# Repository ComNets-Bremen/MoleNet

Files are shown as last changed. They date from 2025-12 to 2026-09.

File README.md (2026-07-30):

# MoleNet: A Wireless Underground Sensor Network Platform

MoleNet Logo

**MoleNet** is a versatile Wireless Underground Sensor Network (WUSN) platform designed for education and low-power environmental monitoring.
This repository contains all relevant resources, including PCB layouts, source code, and examples to test and evaluate the platform.

Further information can be found on the official [MoleNet Website](https://molenet.org/)!

> ⚠️ **Note:** This is an active project. The files and directory structure are subject to change.

## New ESP32-based MoleNet!

After a long journey, we are finally at a point where we are testing the current version on a larger scale.
The latest version of MoleNet features several key improvements:

- **ESP32-S3 microcontroller**: A powerful yet energy-efficient processor that supports various development ecosystems including [MicroPython](https://micropython.org/), [Arduino](https://www.arduino.cc/), and [RiotOS](https://www.riot-os.org/)
- **SDI-12 sensor interface**: Compatible with high-quality environmental sensors
- **Micro-SD card support**: Enables extensive local data storage
- **SX1276-based LoRa transceiver**: Provides long-range wireless communication
- **On-board BME280 sensor**: Measures temperature, barometric pressure, and humidity [BME280](https://www.bosch-sensortec.com/products/environmental-sensors/humidity-sensors-bme280/)
- **Low-power design**: Ensures long battery life for extended deployments
- **qwiic connectivity**: Simplifies integration of I2C-based sensors, as, for
  example, available here: [Sparkfun](https://www.sparkfun.com/qwiic)

## Documentation

New users can start with the **[Getting Started Guide](doc/GETTING_STARTED.md)** to identify their board version and find the correct software, hardware documentation, and setup instructions.

The main documentation of MoleNet is available [here in the doc directory](doc). There, you can also find the **[FAQ](doc/FAQ.md)**.

## Older Versions of MoleNet (pre-ESP)

In the past decade, we used and evaluated different microcontroller platforms
for MoleNet. The documentation can be found in the corresponding directories:

- [For ATMEGA-based boards](doc/ATMEGA)
- [For the STM32-based boards (STM32F411)](doc/stm32)

## Changelog

The list of changes and the evolution of MoleNet is listed in the
[changelog](CHANGELOG.md).

## Publications

The following list gives some MoleNet-related publications:

- Gellhaar, M., Dede, J., Koehler, H., & Förster, A. (2016, February). Design and Evaluation of Underground Wireless Sensor Networks for Reforestation Monitoring. [In EWSN (pp. 229-230)](https://dl.acm.org/doi/10.5555/2893711.2893747).
- Zaman, I., Dede, J., Gellhaar, M., Koehler, H., & Foerster, A. (2016). Molenet: A new sensor node for underground monitoring. [IEEE SenseApp](https://www.researchgate.net/publication/309397324_MoleNet_A_New_Sensor_Node_for_Underground_Monitoring).
- Zaman, I., Gellhaar, M., Dede, J., Koehler, H., & Foerster, A. (2016, November). Design and evaluation of MoleNet for wireless underground sensor networks. In 2016 IEEE 41st conference on local computer networks workshops (LCN workshops) (pp. 145-147), [2016 IEEE 41st Conference on Local Computer Networks Workshops (LCN Workshops), Dubai, United Arab Emirates, 2016, pp. 145-147](https://doi.org/10.1109/LCN.2016.040).
- Dede, J., Helms, D., & Förster, A. (2021). MoleNet: An Underground Sensor Network for Soil Monitoring. [Electronic Communications of the EASST, 80](https://doi.org/10.14279/tuj.eceasst.80.1132)
- Sambo, D. W., Dede, J., Mitton, N., & Förster, A. (2023). FuzDeMa: A portable Fuzzy-based Decision-Making tool for reliable communication in Wireless Underground Sensor Networks. [ITU Journal on Future and Evolving Technologies, 4(3), 419-433](https://www.doi.org/10.52953/IXIP2995).
- Block, J., Könsgen, A., Dede, J., Förster, A. (2026, January). Precise Low-Current Measurement Techniques for IoT Devices: A Case Study on MoleNet. [arxiv, Electrical Engineering and Systems Science > Signal Processing](https://doi.org/10.48550/arXiv.2601.16727)

## I need Support or want to Contribute!

The development of MoleNet is mainly done on GitHub. You have the following
channels:

- For discussions, we are currently trying to move from our mailing list to [GitHub discussions](https://github.com/ComNets-Bremen/MoleNet/discussions). Feel free to join and open new discussions directly [here](https://github.com/ComNets-Bremen/MoleNet/discussions)!
- You found an issue? [Open an Issue on GitHub](https://github.com/ComNets-Bremen/MoleNet/issues)!
- You already have a solution? Perfect! Feel free to [create a Pull request on GitHub](https://github.com/ComNets-Bremen/MoleNet/pulls)!

If you need support with the git fundamentals like cloning, forking, branching,
the different copies of the code etc., please refer to the [GitHub
documentation](https://docs.github.com).

## I want to have MoleNet!

MoleNet is a dynamic project that is constantly evolving. At its current stage, we do not offer a ready-to-use, fully certified product with complete end-user support.

If you would like to contribute to the development of MoleNet and need hardware for testing and further development, you have two options:

1. **Build the hardware yourself.** All the necessary resources can be found in this repository.
2. **Order evaluation boards** from our partner [Intergalactic Circuits](https://intergalactic-circuits.de) for personal use.

## Contributors

Many students and researchers contribute to the MoleNet project.
See the full list of contributors in [CONTRIBUTORS.md](CONTRIBUTORS.md).

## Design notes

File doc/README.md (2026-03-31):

# Documentation

This directory contains the documentation of MoleNet. For the previous
versions, please refer to the [ATMEGA](ATMEGA) or [stm32](stm32) directory, respectively.

Maybe you are looking for our **[FAQ](FAQ.md)**?

# The Hardware

MoleNet 6.1 with all available components assembled. Click on the image for a
high resolution version.

The MoleNet 6.3 hardware

## Available Components

- LoRa via
  - [SX1276](https://www.semtech.com/products/wireless-rf/lora-connect/sx1276) [Ra-01H](https://docs.ai-thinker.com/en/Ra-01H/) module till MoleNet 6.3
  - [SX1262](https://www.semtech.com/products/wireless-rf/lora-connect/sx1262) [RA-01SH](https://docs.ai-thinker.com/en/Ra-01SH/index.html) module since MoleNet 7.0
- [BME280](https://www.bosch-sensortec.com/products/environmental-sensors/humidity-sensors-bme280/)
- SD-card holder
- [qwiic](https://www.sparkfun.com/qwiic) for external I2C components
- LEDs
- [SDI-12](https://www.sdi-12.org/) for environmental sensors
- Additional pins (analog and digital)

## Components and their Connections

MoleNet contains various different on-board parts. The following tables list
the connections and other relevant information for the major parts. For further
details, refer to [schematics of the corresponding board](../PCB-Layouts/).

- [Table MoleNet 7.1](hw_doc/7.1.md)
- [Table MoleNet 7.0](hw_doc/7.0.md)
- [Table MoleNet 6.3](hw_doc/6.3.md)
- [Table MoleNet 6.2](hw_doc/6.2.md)

**Please check also the [CHANGELOG](../CHANGELOG.md) for further changes and issues**

## Pins on the ESP32

For the usage of the pins, please refer to the hardware section in this
document or the schematics of the corresponding versions available in [the PCB-Layouts directory](../PCB-Layouts/).

# Setup using Arduino

1) Install **Arduino IDE** -> [arduino.cc](https://www.arduino.cc/en/software/)
2) Install the **esp32** package by Espressif via the **Boards Manager** in the IDE
3) Select the **ESP32S3 Dev Module** as the board
4) Select the corresponding USB port
5) Set USB CDC On Boot: Enabled
6) Set USB Mode: USB-OTG (Tiny USB)

**⚠️ Attention: Different ports!**

Different ports are created at various times when the MoleNet platform is connected to the computer. One port is to flash the firmware, while the second is to access the MoleNet Platform’s serial port. The first is the default after a reset. The second is usually entered if the boot button is pressed during reset or when powering up the board.

Usually, you have to setup the board twice according to the settings above. Be
aware that the port identifier can change depending on your operating system.

# Setup using MicroPython

Please use the documentation for the ESP32 available at
[micropython.org](https://micropython.org/download/ESP32_GENERIC_S3/).

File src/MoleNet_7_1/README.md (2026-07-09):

# MoleNet v7.1 Test Files

This folder contains basic test files for the MoleNet v7.1 ESP32-S3 board.

## Folder Structure

* `lib/`
  Common MicroPython libraries used by the test scripts.

* `deep_sleep_test/`
  Minimal test to measure board + LoRa deep sleep current.

* `lorawan_connection_test/`
  Minimal ABP and OTAA scripts to test LoRaWAN connection with TTN.

## Notes

* The `lib/` folder does not contain `main.py`.
* Use only one test script as `main.py` on the board at a time.
* Copy the required files from `lib/` to the board together with the selected test script.
* The onboard BME280 is not used in these minimal tests.
* External sensors are not required for these tests.

## Included Tests

### Deep Sleep Test

Used to measure the deep sleep current of:

* MoleNet board + LoRa module
* MoleNet board only, if LoRa VDD / RA_VDD is disconnected

### LoRaWAN Connection Test

Used to check if the MoleNet v7.1 board can send data to TTN using:

* ABP
* OTAA

The LoRaWAN test sends:

`hello`

to TTN.

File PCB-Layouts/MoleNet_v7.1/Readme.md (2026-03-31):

This folder contain Kicad files of Molenet V7.1 Board.

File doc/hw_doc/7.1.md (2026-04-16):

# Components and their Connections: MoleNet 7.1

This table gives an overview of the used components and their connections.
Please also refer to the corresponding schematic:

[MoleNet 7.1 Schematic](../../PCB-Layouts/MoleNet_v7.1/Molenet_V7.1_Schematic.pdf)

| **Part** | **Part Number** | **Description** | **Pins** |
|---|---|---|---|
| SW1 | SKHHARA010 | Reset button (enable) for ESP32 | EN |
| SW2 | SKHHARA010 | Boot mode button for ESP32 | GPIO0 |
| U1 | [ESP32-S3-WROOM-1-N16](https://www.espressif.com/sites/default/files/documentation/esp32-s3-wroom-1_wroom-1u_datasheet_en.pdf) | ESP32-S3 | |
| U3 | [TLV76133DCYR](https://www.ti.com/product/de-de/TLV761/part-details/TLV76133DCYR) | Voltage regulator 3V3, 1N5819 between Vin and the regulator (D1) | |
| U5 | Ra-01SH | LoRa Module ([SX1262](https://www.semtech.com/products/wireless-rf/lora-connect/sx1262), [RA-01SH](https://docs.ai-thinker.com/en/Ra-01SH/index.html)) | RESET=GPIO15, NSS=GPIO48, MOSI=GPIO47, MISO=GPIO21, SCK=GPIO14, DIO1=GPIO46, BUSY/DIO4=GPIO39 |
| U7 | [BME280](https://www.bosch-sensortec.com/products/environmental-sensors/humidity-sensors-bme280/) | Sensor for humidity, barometric pressure and ambient temperature | I2C, SCL=GPIO8, SDA=GPIO9, address=0x76 (shared with qwiic connector) |
| D6 | NCD0805R1 | User LED | GPIO38 |
| D7 | NCD0805R1 | User LED | GPIO2 |
| D8 | NCD0805R1 | Power LED | Power |
| J1 | | Enable SD-card via jumpers | Power=GPIO7 (optional), MOSI=GPIO11, MISO=GPIO13, SCK=GPIO12, CS=GPIO10. You can select the power by one jumper: directly powered or via GPIO. |
| J2 | | Enable BME280 connection via jumpers | |
| J3 | | Power out | 2xGND, 3V3, Vin |
| J4 | | Enable LEDs via jumpers | |
| J5 | | Enable LoRa via jumpers | |
| J6 | | USB connector. Uses the ESP32 internal USB (D+, D-), use USB-CDC on boot / USB-OTG with TinyUSB (depending on your needs / system)| |
| J7 | | Power in, 5-7V | |
| J8 | | Misc. pins (ADC etc.) | |
| J9 | | Unused GPIOs | |
| J10 | | SDI-12 connector | Uses the following GPIOs: Power=GPIO1, SDI_RX_ENABLE=GPIO36, SDI_RX=GPIO18, SDI_TX_ENABLE=GPIO35, SDI_TX=GPIO17, SDI_MARKING=GPIO37 |
| J11 | | Remaining DIOs from LoRa transceiver | |
| J12 | | Power connector for energy measurements of the entire board. Connect via jumper | |
| J13 | | Micro SD card holder | |
| J14 | SMA-KWE902 | SMA connector for LoRa | |
| J15 | | qwiic connector for I2C devices | SCL=GPIO8, SDA=GPIO9 (shared with BME280) |
| J16 | | Power SDI-12 interface via jumper. Alternative: switch using GPIO1 | |
| J17 | | Jumper for ESP32 power supply. Used to measure only the power consumption of the ESP. Connect via jumper. | |

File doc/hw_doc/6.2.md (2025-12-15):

# Components and their Connections: MoleNet 6.2

This table gives an overview of the used components and their connections.
Please also refer to the corresponding schematic:

[MoleNet 6.2 Schematic](../../PCB-Layouts/MoleNet_v6.2/MoleNet V6.2/Molenet_V6.2_20_03_25_schematic.pdf)

| **Part** | **Part Number** | **Description** | **Pins** |
|---|---|---|---|
| SW1 | SKHHARA010 | Reset button (enable) for ESP32 | EN |
| SW2 | SKHHARA010 | Boot mode button for ESP32 | GPIO0 |
| U1 | [ESP32-S3-WROOM-1-N16](https://www.espressif.com/sites/default/files/documentation/esp32-s3-wroom-1_wroom-1u_datasheet_en.pdf) | ESP32-S3 | |
| U3 | [TLV76133DCYR](https://www.ti.com/product/de-de/TLV761/part-details/TLV76133DCYR) | Voltage regulator 3V3 | |
| U5 | Ra-01H | LoRa Module ([SX1276](https://www.semtech.com/products/wireless-rf/lora-connect/sx1276)) | RESET=GPIO55, NSS=GPIO48, MOSI=GPIO47, MISO=GPIO21, SCK=GPIO14, DIO0=GPIO46 |
| U7 | [BME280](https://www.bosch-sensortec.com/products/environmental-sensors/humidity-sensors-bme280/) | Sensor for humidity, barometric pressure and ambient temperature | I2C, SCL=GPIO8, SDA=GPIO9, address=0x76 |
| D6 | NCD0805R1 | User LED | GPIO38 |
| D7 | NCD0805R1 | User LED | GPIO2 |
| D8 | NCD0805R1 | Power LED | Power |
| J1 | | Enable SD-card via jumpers | Power=GPIO7 (optional), MOSI=GPIO11, MISO=GPIO13, SCK=GPIO12, CS=GPIO10 |
| J2 | | Enable BME280 connection via jumpers | |
| J3 | | Power out | GND, 3V3, Vin |
| J4 | | Enable LEDs via jumpers | |
| J5 | | Enable LoRa via jumpers | |
| J6 | | USB connector | |
| J7 | | Power in | |
| J8 | | Misc. pins (ADC etc.) | |
| J9 | | Unused GPIOs | |
| J10 | | SDI-12 connector | Uses the following GPIOs: Power=GPIO1, SDI_RX_ENABLE=GPIO36, SDI_RX=GPIO18, SDI_TX_ENABLE=GPIO35, SDI_TX=GPIO17, SDI_MARKING=GPIO37 |
| J11 | | Remaining DIOs from LoRa transceiver | |
| J12 | | Power connector for energy measurements of the entire board. Connect via jumper | |
| J13 | | Micro SD card holder | |
| J14 | SMA-KWE902 | SMA connector for LoRa | |
| J15 | | qwiic connector for I2C devices | SCL=GPIO8, SDA=GPIO9 (shared with BME280) |
| J16 | | Power SDI-12 interface via jumper. Alternative: switch using GPIO1 | |
| J17 | | Jumper for ESP32 power supply. Used to measure only the power consumption of the ESP. Connect via jumper. | |

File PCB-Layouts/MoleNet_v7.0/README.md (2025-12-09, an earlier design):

This folder contain Kicad files of Molenet V7 Board.

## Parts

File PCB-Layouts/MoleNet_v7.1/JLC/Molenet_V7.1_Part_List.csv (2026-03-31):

Designator | Footprint | Quantity | Value | JLC Part Number | Alternative
C1, C14 | 0805 | 2 | 22uF | C45783
C10, C5, C7, C9 | 0805 | 4 | 0.1uF | C49678
C13 | 0805 | 1 | 10uF | C15850
C15, C2 | 0805 | 2 | 100nF | C49678
C16 | 0402 | 1 | 22uF | C415703
C17 | 0402 | 1 | 100nF | C1525
C3, C6, C8 | 0805 | 3 | 1uF | C28323
C4 | 0805 | 1 | 2.2uF | C377773
D1, D3 | D_DO-41_SOD81_P10.16mm_Horizontal | 2 | 1N5819 | C2474
D2, D4, D5 | LESD5D50CT1G | 3 | LESD5D5.0CT1G | C383211 | C5199850
D6, D7, D8 | 0805 | 3 | LED | C84256
H1, H2, H3, H4 | MountingHole_3.2mm_M3_Pad | 4 | MountingHole_Pad
J1 | PinHeader_2x07_P2.54mm_Vertical | 1 | Micro SD connector | C71397
J10 | TerminalBlock_Phoenix_PT-1,5-3-3.5-H_1x03_P3.50mm_Horizontal | 1 | SDI-12 | C91152
J11 | PinHeader_1x06_P2.54mm_Vertical | 1 | RA_01_DIO | C6332199
J12, J16, J17 | PinHeader_1x02_P2.54mm_Vertical | 3 | Conn_01x02 | C492401
J13 | microSD_HC_Molex_104031-0811 | 1 | Micro SD Card | C428492 | C585350
J14 | SMA_Amphenol_901-143_Horizontal | 1 | Conn_Coaxial | C914554 | C1509213
J15 | SPARKFUN_PRT-14417 | 1 | Qwiic | C2859067 | C160404
J2 | PinHeader_2x04_P2.54mm_Vertical | 1 | BME280 Connector | C18078213
J3 | PinHeader_1x04_P2.54mm_Vertical | 1 | Power Out | C2691448
J4 | PinHeader_2x03_P2.54mm_Vertical | 1 | Led Connector | C7501274
J5 | PinHeader_2x08_P2.54mm_Vertical | 1 | Lora Connector | C18078217
J6 | USB_C_Receptacle_G-Switch_GT-USB-7010ASV | 1 | USB_C_Receptacle_USB2.0 | C2936185
J7 | TerminalBlock_Phoenix_PT-1,5-2-3.5-H_1x02_P3.50mm_Horizontal | 1 | 5V-16V Input | C695629
J8 | PinHeader_2x04_P2.54mm_Vertical | 1 | ~ | C18078213
J9 | PinHeader_2x08_P2.54mm_Vertical | 1 | Unused Pin | C18078217
Q1 | TO-92_Inline | 1 | BS170 | C111691
Q2 | SOT-23 | 1 | IRLML5203 | C5364310
R1, R2, R3, R6 | 0805 | 4 | 10k | C17414
R10, R11, R12, R8 | 0805 | 4 | 220 | C17557
R13, R14, R15, R16 | 0402 | 4 | 10K | C25744
R17, R7 | 0402 | 2 | 4.7K | C25900
R18, R19 | 0805 | 2 | 100k | C149504
R4, R5 | 0402 | 2 | 5.1k | C25905
R9 | 0805 | 1 | 1k | C17513
SW1 | SW_PUSH_6mm_H4.3mm | 1 | RESET | C139758 | C7470125
SW2 | SW_PUSH_6mm_H4.3mm | 1 | BOOT | C139758
U1 | ESP32-S3-WROOM-1 | 1 | ESP32-S3-WROOM-1 | C2913199
U2 | SC-74A-5_1.55x2.9mm_P0.95mm | 1 | 74AHC1G00 | C842261
U3 | SOT-223-3_TabPin2 | 1 | TLV76133DCY | C7527500
U4 | DIP-4_W7.62mm | 1 | PC817 | C3025068
U5 | Ai-Thinker-Ra-01-LoRa | 1 | Lora Module | C2764087
U6 | SOP65P400X130-8N | 1 | 74LVC2G241 | C2676069
U7 | Bosch_LGA-8_2.5x2.5mm_P0.65mm_ClockwisePinNumbering | 1 | BME280 | C92489

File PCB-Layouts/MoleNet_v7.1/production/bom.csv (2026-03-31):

Designator | Footprint | Quantity | Value | LCSC Part #
C1, C14 | 0805 | 2 | 22uF
C10, C5, C7, C9 | 0805 | 4 | 0.1uF
C13 | 0805 | 1 | 10uF
C15, C2 | 0805 | 2 | 100nF
C16 | 0402 | 1 | 22uF
C17 | 0402 | 1 | 100nF
C3, C6, C8 | 0805 | 3 | 1uF
C4 | 0805 | 1 | 2.2uF
D1, D3 | D_DO-41_SOD81_P10.16mm_Horizontal | 2 | 1N5819
D2, D4, D5 | LESD5D50CT1G | 3 | LESD5D5.0CT1G
D6, D7, D8 | 0805 | 3 | LED
H1, H2, H3, H4 | MountingHole_3.2mm_M3_Pad | 4 | MountingHole_Pad
J1 | PinHeader_2x07_P2.54mm_Vertical | 1 | Micro SD connector
J10 | TerminalBlock_Phoenix_PT-1,5-3-3.5-H_1x03_P3.50mm_Horizontal | 1 | SDI-12
J11 | PinHeader_1x06_P2.54mm_Vertical | 1 | RA_01_DIO
J12, J16, J17 | PinHeader_1x02_P2.54mm_Vertical | 3 | Conn_01x02
J13 | microSD_HC_Molex_104031-0811 | 1 | Micro SD Card
J14 | SMA_Amphenol_901-143_Horizontal | 1 | Conn_Coaxial
J15 | SPARKFUN_PRT-14417 | 1 | Qwiic
J2 | PinHeader_2x04_P2.54mm_Vertical | 1 | BME280 Connector
J3 | PinHeader_1x04_P2.54mm_Vertical | 1 | Power Out
J4 | PinHeader_2x03_P2.54mm_Vertical | 1 | Led Connector
J5 | PinHeader_2x08_P2.54mm_Vertical | 1 | Lora Connector
J6 | USB_C_Receptacle_G-Switch_GT-USB-7010ASV | 1 | USB_C_Receptacle_USB2.0
J7 | TerminalBlock_Phoenix_PT-1,5-2-3.5-H_1x02_P3.50mm_Horizontal | 1 | 5V-16V Input
J8 | PinHeader_2x04_P2.54mm_Vertical | 1 | ~
J9 | PinHeader_2x08_P2.54mm_Vertical | 1 | Unused Pin
Q1 | TO-92_Inline | 1 | BS170
Q2 | SOT-23 | 1 | IRLML5203
R1, R2, R3, R6 | 0805 | 4 | 10k
R10, R11, R12, R8 | 0805 | 4 | 220
R13, R14, R15, R16 | 0402 | 4 | 10K
R17, R7 | 0402 | 2 | 4.7K
R18, R19 | 0805 | 2 | 100k
R4, R5 | 0402 | 2 | 5.1k
R9 | 0805 | 1 | 1k
SW1 | SW_PUSH_6mm_H4.3mm | 1 | RESET
SW2 | SW_PUSH_6mm_H4.3mm | 1 | BOOT
U1 | ESP32-S3-WROOM-1 | 1 | ESP32-S3-WROOM-1
U2 | SC-74A-5_1.55x2.9mm_P0.95mm | 1 | 74AHC1G00
U3 | SOT-223-3_TabPin2 | 1 | TLV76133DCY
U4 | DIP-4_W7.62mm | 1 | PC817
U5 | Ai-Thinker-Ra-01-LoRa | 1 | Lora Module
U6 | SOP65P400X130-8N | 1 | 74LVC2G241
U7 | Bosch_LGA-8_2.5x2.5mm_P0.65mm_ClockwisePinNumbering | 1 | BME280

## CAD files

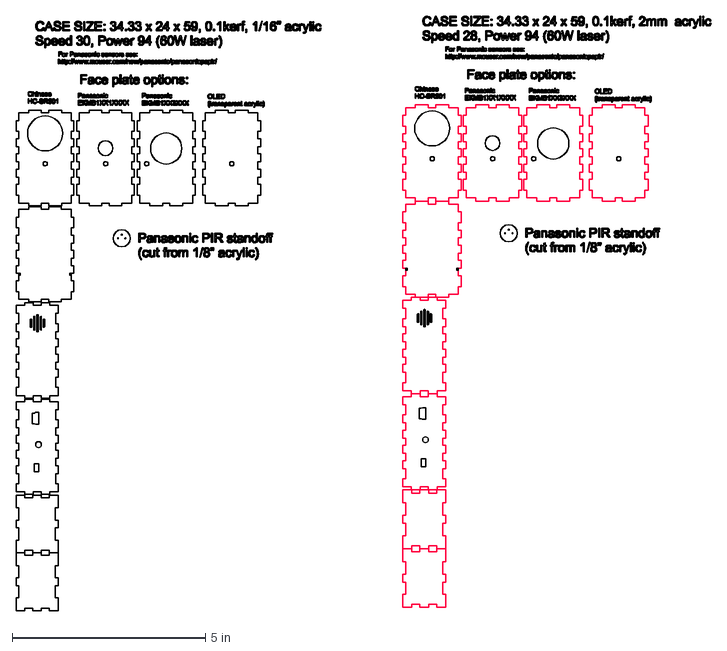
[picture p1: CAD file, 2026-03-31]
experiments/2024-LoRa_Gateway_for_WUSN/Modified Libraries/RFM69_LowPowerLab/Examples/MotionMote/LasercutCase_R3.dxf
18.0 x 15.4 in

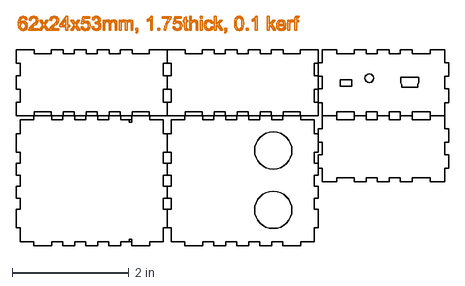
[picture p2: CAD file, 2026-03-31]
experiments/2024-LoRa_Gateway_for_WUSN/Modified Libraries/RFM69_LowPowerLab/Examples/SonarMote/SonarMote_lasercut plans_1.75mm acrylic.dxf
7.41 x 3.94 in

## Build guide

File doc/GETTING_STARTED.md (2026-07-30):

# Getting Started with MoleNet

Welcome to MoleNet! This guide helps you identify your MoleNet board version and find the corresponding software, hardware documentation, experiments, schematics, and setup resources.

---

## Step 1: Identify Your Hardware Version

Look at the version number printed on the green silkscreen of your MoleNet board.

Examples include:

* `MoleNet v7.1`
* `MoleNet v7.0`
* `MoleNet v6.3`
* `MoleNet v6.2`
* `MoleNet v6.1`
* `MoleNet v6.0`

Use this version number to select the correct software and hardware documentation in the following sections.

---

## Step 2: Access the MoleNet Code

The MoleNet source code and documentation are available in this GitHub repository.

You can access the repository in the following ways:

* Browse the files directly on GitHub.
* Download the repository as a ZIP file.
* Clone the repository using Git.

If you are new to Git and GitHub, the following resources explain how to clone repositories, work with branches, commit changes, and push code:

* [GitHub Git Handbook](https://docs.github.com/en/get-started/start-your-journey/git-handbook): A short introduction to Git concepts and commands.
* [Cloning a GitHub Repository](https://docs.github.com/en/repositories/creating-and-managing-repositories/cloning-a-repository): Instructions for cloning a repository to your computer.
* [Atlassian Git Tutorials](https://www.atlassian.com/git/tutorials): Detailed tutorials about Git workflows and collaboration.

---

## Step 3: Find the Correct Software and Hardware Documentation

Go to the [`src`](../src) directory and select the appropriate software folder for your board version.

> Before assigning GPIO pins in your code, check the hardware documentation for your board version. Some pins are already connected to onboard components and may not be available for general use.

### MoleNet v7.1

* MCU: ESP32-S3
* LoRa chip: SX1262 / RA-01SH
* Software folder: [`src/MoleNet_7_1`](../src/MoleNet_7_1)
* Hardware documentation: [`hw_doc/7.1.md`](./hw_doc/7.1.md)
* Contains: MicroPython board test scripts, LoRaWAN setup files, power-measurement files, drivers, and setup guides.

### MoleNet v7.0

* MCU: ESP32-S3
* LoRa chip: SX1262 / RA-01SH
* Software folder: [`src/MoleNet_7.0`](../src/MoleNet_7.0)
* Hardware documentation: [`hw_doc/7.0.md`](./hw_doc/7.0.md)
* Contains: MicroPython test scripts and required drivers.

### MoleNet v6.1, v6.2, and v6.3

* MCU: ESP32-S3
* LoRa chip: SX1276 / RA-01H
* Software folder: [`src/MoleNet_6.1`](../src/MoleNet_6.1)

These board versions use similar software. However, the LoRa reset pin must be configured according to the board version.

| Board version | `LORA_RST` | Hardware documentation |
| --- | ---: | --- |
| MoleNet v6.1  | `45` | No separate hardware Markdown file is currently available |
| MoleNet v6.2  | `55` | [`hw_doc/6.2.md`](./hw_doc/6.2.md) |
| MoleNet v6.3  | `15` | [`hw_doc/6.3.md`](./hw_doc/6.3.md) |

Before using additional GPIO pins, verify their availability using the corresponding hardware documentation, PCB layout, or schematic.

### MoleNet v6.0

* MCU: ESP32-S3
* LoRa chip: SX1276 / RA-01H
* Software folder: [`src/MoleNet_6.0`](../src/MoleNet_6.0)
* Contains: Arduino and MicroPython test code.
* Hardware documentation: No separate hardware Markdown file is currently available. See the [`PCB-Layouts`](../PCB-Layouts) directory for schematics and PCB files.

### STM32-Based Boards

* Setup and flashing instructions: [`stm32`](./stm32)

Follow the documentation in this folder to configure and flash STM32-based MoleNet boards.

### Legacy ATMEGA-Based Boards

* MCU: ATmega328P
* Radio: RFM69
* Software folder: [`src/ATMEGA-based`](../src/ATMEGA-based)
* Documentation: [`ATMEGA`](./ATMEGA)

---

## Step 4: Find General Documentation

The [`doc`](./) directory contains the general MoleNet documentation.

Useful folders and files include:

* [`FAQ.md`](./FAQ.md): General questions and answers about MoleNet design and usage.
* [`hw_doc`](./hw_doc): Hardware documentation and pin mappings for different MoleNet versions.
* [`stm32`](./stm32): STM32 board setup and flashing documentation.
* [`ATMEGA`](./ATMEGA): Documentation for legacy ATMEGA-based boards.

---

## Step 5: Find Experiments and Measurements

Go to the [`experiments`](../experiments) directory for experimental setups, results, and measurement data.

Examples include:

* [`2026-power-consumption-and-voltage-measurement`](../experiments/2026-power-consumption-and-voltage-measurement): Power-consumption and voltage-measurement results.
* [`2025-EWSN_Water_Sensors`](../experiments/2025-EWSN_Water_Sensors): Water-sensor experiments.
* [`2024-LoRa_Gateway_for_WUSN`](../experiments/2024-LoRa_Gateway_for_WUSN): LoRa gateway setup and related files.
* [`data_rangetest`](../experiments/data_rangetest): Wireless range-test data.

---

## Step 6: Find Schematics, PCB Files, and Enclosures

The following directories contain hardware design files and mechanical components:

* [`PCB-Layouts`](../PCB-Layouts): Schematics and KiCad PCB design files.
* [`PCB-Enclosures`](../PCB-Enclosures): 3D-printable cases, holders, and stands.
* [`Auxiliary Boards`](../Auxiliary%20Boards): Additional hardware boards and supporting circuit designs.

Use the PCB schematics and hardware documentation to verify pin connections before modifying the software or connecting additional components.

---

## Step 7: Flashing and Maintenance Tools

For ESP32 board flashing, firmware installation, and hardware testing, use:

* [`tools/MoleWarden`](../tools/MoleWarden): MoleNet tools for erasing, flashing, configuring, and testing supported boards.

Follow the README file inside the `MoleWarden` folder for installation and usage instructions.

For direct command-line flashing of Espressif devices, see:

* [esptool Documentation](https://docs.espressif.com/projects/esptool/en/latest/): Official documentation for erasing and flashing ESP32 devices.

---

## Step 8: MicroPython Setup and External Documentation

The official MicroPython documentation contains instructions for installing or updating MicroPython firmware, uploading code, accessing the REPL, and using ESP32 hardware peripherals.

### MicroPython Documentation

* [MicroPython Official Documentation](https://docs.micropython.org/): General MicroPython documentation and library references.
* [Getting Started with MicroPython on ESP32](https://docs.micropython.org/en/latest/esp32/tutorial/intro.html): Instructions for installing firmware, flashing an ESP32 board, accessing the serial REPL, and troubleshooting.
* [MicroPython ESP32 Quick Reference](https://docs.micropython.org/en/latest/esp32/quickref.html): Examples for GPIO, I²C, SPI, UART, timers, deep sleep, and other ESP32 features.
* [`mpremote` Documentation](https://docs.micropython.org/en/latest/reference/mpremote.html): Command-line tool for connecting to MicroPython devices, uploading files, and running scripts.

### Optional IDE

[Thonny IDE](https://thonny.org/) can be used to:

* Connect to a MicroPython board.
* Access the MicroPython REPL.
* Upload and download files.
* Edit and run Python scripts directly on the board.

The MoleNet-specific flashing and testing procedures provided in this repository should be followed where available.

---

## Need Help?

If you are unsure which software folder, hardware document, or flashing procedure applies to your board:

1. Confirm the version printed on the board.
2. Check the corresponding hardware documentation.
3. Check the README file inside the relevant software folder.
4. Review the [`FAQ`](./FAQ.md).
5. Open an issue in the MoleNet GitHub repository if the required information is missing.

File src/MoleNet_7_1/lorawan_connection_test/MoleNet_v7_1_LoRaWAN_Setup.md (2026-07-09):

# MoleNet v7.1 LoRaWAN Setup Guide

## Part A - Connect MoleNet Board to LoRaWAN

### Step 1. Confirm LoRa Hardware

Check the MoleNet v7.1 schematic and confirm the LoRa module.

- Module: RA-01SH
- Chip: SX1262
- Driver file: `SX1262.py`

Use `SX1262.py` as the driver for the LoRa module.

### Step 2. Install Thonny

Download and install Thonny on your laptop from:

```text
thonny.org
```

Thonny is used to flash MicroPython, upload files to the MoleNet board, and run the program.

### Step 3. Flash MicroPython

Flash MicroPython for ESP32-S3 to the MoleNet board.

In Thonny:

- Go to `Tools -> Options -> Interpreter`
- Choose `MicroPython (ESP32)`
- Select the correct COM port
- Click `Install or update MicroPython` if needed
- Select the `ESP32_GENERIC_S3` firmware

After flashing, the Thonny shell should show:

```text
>>>
```

This means the board is ready to run MicroPython code.

### Step 4. Prepare Files on Laptop

Keep these files together in one folder on your laptop:

- `SX1262.py`
- `LoRaWAN.py`
- `EU868.py`
- `config_ABP.py`
- `cmac.py`

Later, `main.py` will also be added to the same folder.

### Step 5. Create TTN Account

Create or log in to an account at The Things Network using the TTN Console.

Use:

```text
thethingsnetwork.org
```

### Step 6. Create TTN Application

Open The Things Network Console.

Go to:

```text
Applications -> Add application
```

Create a new application for the MoleNet device.

Use a clear application name, for example:

```text
molenet-test
```

### Step 7. Generate a Unique Device ID

Connect the MoleNet board in Thonny and run:

```python
import machine
import binascii

device_id = "molenet-" + binascii.hexlify(machine.unique_id()).decode()
print(device_id)
```

Use the printed value as the **End device ID** in TTN.

### Step 8. Register End Device

Register the device manually with the following settings:

- Frequency plan: `Europe 863-870 MHz`
- LoRaWAN version: `1.0.4`
- Regional Parameters version: `RP002 1.0.4`
- Activation mode: `ABP`
- End device ID: use the value generated in Step 7

Use ABP for this simple LoRaWAN connection test.

### Step 9. Generate TTN Keys

Generate and copy the following values from TTN:

- `DevEUI`
- `DevAddr`
- `AppSKey`
- `NwkSKey`

These values are needed in `config_ABP.py`.

### Step 10. Add TTN Keys to config_ABP.py

Create or open the file:

```text
config_ABP.py
```

Paste the TTN values into `config_ABP.py`. A simple format is:

```python
import ubinascii

DevEUI = ubinascii.unhexlify("PASTE_DEVEUI_HERE")
DevAddr = ubinascii.unhexlify("PASTE_DEVADDR_HERE")
AppSKey = ubinascii.unhexlify("PASTE_APPSKEY_HERE")
NwkSKey = ubinascii.unhexlify("PASTE_NWKSKEY_HERE")
```

Example for `DevAddr`:

```python
DevAddr = ubinascii.unhexlify("260B304C")
```

Using `ubinascii.unhexlify()` is easier than manually writing byte arrays such as:

```python
DevAddr = [0x26, 0x0B, 0x30, 0x4C]
```

Make sure there are no spaces inside the key strings.

### Step 11. Write main.py

Create a file named `main.py` and paste the following code:

```python
from machine import SoftSPI, Pin
from SX1262 import Transceiver
from LoRaWAN import LoRaWAN
from config_ABP import NwkSKey, AppSKey, DevAddr, DevEUI
import EU868
import utime

utime.sleep_ms(200)

spi = SoftSPI(
    baudrate=100000,
    sck=Pin(14),
    mosi=Pin(47),
    miso=Pin(21)
)

cs = Pin(48, Pin.OUT, value=1)
rst = Pin(15, Pin.OUT, value=1)
busy = Pin(39, Pin.IN)
dio1 = Pin(46, Pin.IN)

sx = Transceiver(spi, cs, rst, busy, dio1)
lw = LoRaWAN(sx, EU868.FREQS)

lw.setup_abp(NwkSKey, AppSKey, DevAddr, DevEUI)

print("LoRaWAN ready")

while True:
    try:
        lw.send("hello", power=17, sf=7)
        print("sent")
    except Exception as e:
        print("send error:", e)

    utime.sleep(60)
```

This code sends the message `hello` every 60 seconds.

### Step 12. SX1262 Pin Mapping

The working SX1262 pin mapping for MoleNet v7.1 is:

| Signal | GPIO |
|---|---:|
| SCK | GPIO14 |
| MOSI | GPIO47 |
| MISO | GPIO21 |
| CS | GPIO48 |
| RST | GPIO15 |
| BUSY | GPIO39 |
| DIO1 | GPIO46 |

Use these pins in the LoRaWAN code.

## Part B - Upload Files via Thonny

### Step 13. Open File Pane

In Thonny, click:

```text
View -> Files
```

The file window shows two sides:

- Left side: laptop file system
- Right side: MicroPython device

### Step 14. Open Your Laptop Folder

In the left pane, navigate to the folder containing:

- `SX1262.py`
- `LoRaWAN.py`
- `EU868.py`
- `config_ABP.py`
- `cmac.py`
- `main.py`

### Step 15. Upload Files to the Board

For each file, right-click it in the left pane and select:

```text
Upload to /
```

Upload all six files:

- `SX1262.py`
- `LoRaWAN.py`
- `EU868.py`
- `config_ABP.py`
- `cmac.py`
- `main.py`

### Step 16. Verify Uploaded Files

In the right panel under the MicroPython device, confirm that all six files are present.

### Step 17. Run main.py

In Thonny:

- Double-click `main.py` on the board side
- Click the green `Run` button

### Step 18. Confirm in Thonny Shell

The Thonny shell should output:

```text
LoRaWAN ready
sent
```

If this appears, the program is running and the board is trying to send LoRaWAN packets.

### Step 19. Confirm in TTN

In The Things Network Console, go to:

```text
Applications -> your application -> your device -> Live data
```

Confirm that TTN shows a new uplink message.

For the `hello` test, the payload will be:

```text
68 65 6C 6C 6F
```

This decodes to:

```text
hello
```

At this point, the basic LoRaWAN connection is complete.

For a simple test, checking the raw payload is enough. For real sensor data, create a payload formatter in TTN. A payload formatter converts the raw payload into readable fields such as temperature, humidity, pressure, and soil moisture.

## Part C - Send TTN Data to Google Sheets

### Step 20. Create Google Sheet

Create a new Google Sheet.

Rename the bottom sheet tab to:

```text
data
```

In row 1, add the following column headers:

- `time`
- `device_id`
- `temp_c`
- `humidity_pct`
- `raw_json`

### Step 21. Open Apps Script

From the Google Sheet, click:

```text
Extensions -> Apps Script
```

This opens the Google Apps Script editor.

### Step 22. Paste Apps Script Code

Delete the default code in Apps Script and paste the following code:

```javascript
function doGet() {
  return ContentService
    .createTextOutput("Webhook is alive")
    .setMimeType(ContentService.MimeType.TEXT);
}

function doPost(e) {
  try {
    const SPREADSHEET_ID = "YOUR_SPREADSHEET_ID";
    const SHEET_NAME = "data";

    const ss = SpreadsheetApp.openById(SPREADSHEET_ID);
    const sheet = ss.getSheetByName(SHEET_NAME);

    if (!sheet) {
      throw new Error('Sheet "data" not found');
    }

    const body = JSON.parse(e.postData.contents);

    const deviceId =
      body.end_device_ids?.device_id ||
      "";

    const time =
      body.uplink_message?.received_at ||
      body.received_at ||
      new Date().toISOString();

    const decoded =
      body.uplink_message?.decoded_payload ||
      {};

    const temp =
      decoded.temp_c ??
      decoded.dht_temp_c ??
      "";

    const hum =
      decoded.humidity_pct ??
      decoded.dht_humidity_pct ??
      "";

    sheet.appendRow([
      time,
      deviceId,
      temp,
      hum,
      JSON.stringify(body)
    ]);

    return ContentService
      .createTextOutput(JSON.stringify({ status: "ok" }))
      .setMimeType(ContentService.MimeType.JSON);

  } catch (err) {
    return ContentService
      .createTextOutput(JSON.stringify({
        status: "error",
        message: String(err)
      }))
      .setMimeType(ContentService.MimeType.JSON);
  }
}
```

This script saves the received time, device ID, decoded temperature, decoded humidity, and the full raw TTN JSON message. The raw JSON is important because the exact field names depend on the TTN payload formatter.

### Step 23. Replace Spreadsheet ID

In the Apps Script code, replace:

```text
YOUR_SPREADSHEET_ID
```

with the actual Spreadsheet ID from the Google Sheet URL.

Example Google Sheet URL:

```text
https://docs.google.com/spreadsheets/d/1abcDEFghiJKLmnop123456789/edit
```

The Spreadsheet ID is the part between `/d/` and `/edit`:

```text
1abcDEFghiJKLmnop123456789
```

So this line:

```javascript
const SPREADSHEET_ID = "YOUR_SPREADSHEET_ID";
```

should become something like:

```javascript
const SPREADSHEET_ID = "1abcDEFghiJKLmnop123456789";
```

### Step 24. Save Apps Script

Save the project using `Ctrl + S` or click the save icon.

### Step 25. Deploy as Web App

In Apps Script:

- Click `Deploy -> New deployment`
- Choose `Web app`
- Set `Execute as = Me`
- Set `Who has access = Anyone`
- Click `Deploy`
- Authorize the project if prompted

After deployment, Google gives a Web App URL.

Important: If the Apps Script code is edited later, save the code and deploy the Web App again. Saving alone is not enough. TTN will continue using the old deployed version unless the script is deployed again.

### Step 26. Copy Web App URL

Copy the Web App URL. It should end with:

```text
/exec
```

Test the URL in a browser. It should display:

```text
Webhook is alive
```

If this message appears, the Web App is active.

### Step 27. Add TTN Webhook

In The Things Network Console, go to:

```text
Applications -> your application -> Integrations -> Webhooks
```

Then select:

```text
Add webhook -> Custom webhook
```

Enter the following settings:

- Webhook ID: `google-sheets`
- Base URL: paste the Apps Script `/exec` URL
- Enable/select: `Uplink message`

Do not enter a custom uplink path unless the TTN form specifically asks for one. The important point is that the webhook must be enabled for uplink messages.

Save the webhook.

### Step 28. Reactivate if Needed

If TTN shows the webhook as deactivated, click `Reactivate`. Then send another uplink message from the board.

### Step 29. Send a New Packet

Let the board send another packet. For the test code, wait for the next 60 second cycle. You can also press reset on the board to restart the program and send again.

### Step 30. Verify in Google Sheet

A new row should appear in the `data` sheet.

The row should contain:

- `time`
- `device_id`
- `temp_c`
- `humidity_pct`
- `raw_json`

If `raw_json` is filled but `temp_c` and `humidity_pct` are empty, the webhook is working. In that case, the issue is that the TTN payload formatter or the field names in Apps Script do not match the actual decoded payload. Check the `raw_json` column and adjust the Apps Script field names if needed.

## Part D - Payload Formatter Note

For the first LoRaWAN test, the board sends only:

```text
hello
```

This confirms that the LoRaWAN connection works.

For real sensor data, use a TTN payload formatter. The payload formatter should decode the raw payload into readable fields.

Example decoded fields can be:

- `temp_c`
- `humidity_pct`
- `pressure_hpa`
- `soil1_moisture`
- `soil1_temp`
- `soil2_moisture`
- `soil2_temp`

After creating or editing a payload formatter in TTN, send a new uplink message and check the TTN Live Data page. If TTN shows `decoded_payload`, then Google Sheets can read those decoded values.

## Part E - Debugging Google Sheets Connection

If Google Sheets does not update, check these steps.

### 1. Test the Web App URL

Open the Apps Script Web App URL in a browser. It should show:

```text
Webhook is alive
```

If it does not show this, the Apps Script deployment is not correct.

### 2. Check TTN Live Data

Go to TTN Live Data and confirm that uplink messages are arriving. If TTN does not receive uplinks, the problem is in the LoRaWAN connection, not in Google Sheets.

### 3. Check Apps Script Executions

In Apps Script, open `Executions`. Check whether the script receives requests. If there is an error, open the failed execution and read the error message.

### 4. Redeploy After Editing

If the Apps Script code was changed, deploy the Web App again.

Use:

```text
Deploy -> Manage deployments -> Edit -> New version -> Deploy
```

Saving the code is not enough.

### 5. Check the raw_json Column

If a row appears in Google Sheets but some decoded fields are empty, check the `raw_json` column. The full TTN message is stored there. Use it to find the correct field names, then update the Apps Script code.

### 6. Optional: Test with Postman

If needed, test the Apps Script Web App URL using Postman. Send a POST request to the Web App `/exec` URL with a sample TTN JSON body. This helps check whether the Apps Script works without waiting for a real LoRaWAN packet.

## Setup Complete

The setup is complete when all of the following are true:

- The board sends packets from Thonny.
- TTN Live Data shows uplink messages.
- Google Sheets receives new rows.
- The `raw_json` column is filled.
- Decoded fields appear if a TTN payload formatter is used.

After this, the MoleNet v7.1 LoRaWAN setup is ready for sensor-data testing.

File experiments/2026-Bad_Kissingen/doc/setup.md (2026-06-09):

Setup
=====

0. Flash the firmware. To do this, go `../../../tools/MoleWarden/` and the version directory of your node. Setup a python `venv` and run `runme.sh` (adjust the USB device setting in `runme.sh` if necessary).
1. Copy all files from this directory and its subdirectory to the device (Molenet). Run `copy-all.sh` from this directory to do so.
2. Register the device as a 'new device' on TTN.
3. Edit the `lib/config_OTAA.py` file and populate it with the data from TTN. It is best to do this using Thonny.
4. Edit `main.py` if necessary to adjust timings, add/remove sensors, or make other program improvements (e.g., using a loop instead of deep sleep).
5. Run the script from the `main.py` view in Thonny.
6. First, check the Thonny output to see if data is being sent; then check TTN to see if data is being received.
7. Switch the payload formatter in TTN to JavaScript and copy the code from `payload_formater.js` (from the TTN directory) into it.
8. Define a webhook (e.g., Google Docs), start a remote MQTT client, or set up another method to utilize the data.
9. Run the device continuously on battery power.

Errors 
------

### Connection canot be established 

1. Maybe you have to delete the internal configuration file for OTAA. See `tnn.md` for additional information.

~~~shell
python ../pyboard.py -d /dev/tty.usbmodem* -f ls
python ../pyboard.py -d /dev/tty.usbmodem1201 -f rm .config.cfg
~~~

2. Maybe you do not have a LoRaWan gateway in the neighborhood. Borrow one, buy one or go to a place where one is reachable.

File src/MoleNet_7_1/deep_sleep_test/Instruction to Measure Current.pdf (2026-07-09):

## Instruction to Measure Current

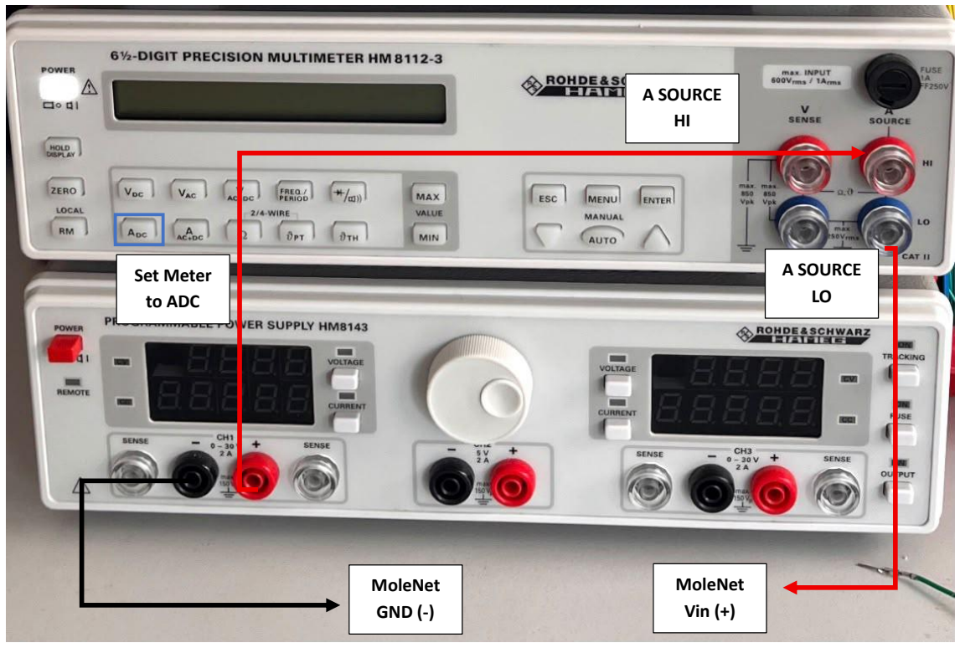
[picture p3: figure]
Set Meter to ADC; MoleNet GND (-); A SOURCE HI; MoleNet Vin (+); A SOURCE LO

Connection steps

1. Set the power supply to 5.0 V.
2. Connect power supply + (red output) to multimeter A SOURCE HI.
3. Connect multimeter A SOURCE LO to MoleNet +Vin. (j7)
4. Connect power supply - (black output) directly to MoleNet GND. (j7)
5. Run the deep sleep test code. Wait until deep sleep, then read the stable current.

Important: The multimeter must be in series. Do not connect it directly across + and GND

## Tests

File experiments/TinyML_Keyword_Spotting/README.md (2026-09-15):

# TinyML Keyword Spotting on MoleNet ESP32-S3

This experiment implements **on-device keyword spotting (KWS)** on the **MoleNet V7.1 ESP32-S3** using an **INMP441 I2S microphone**.

The system recognizes three spoken keywords:

- `YES`
- `NO`
- `UP`

The complete audio-processing and inference pipeline runs locally on the ESP32-S3.

The detected keyword controls the onboard D6 LED:

| Keyword | Action |
|---|---|
| `YES` | D6 LED ON |
| `NO` | D6 LED OFF |
| `UP` | D6 LED blinks 3 times |

---

## System Overview

```text
INMP441 microphone
        |
        v
2-second audio capture
        |
        v
1-second speech-region selection
        |
        v
MFCC feature extraction
        |
        v
INT8 ESP-DL CNN
        |
        v
YES / NO / UP
        |
        v
D6 LED action
```

The firmware records two seconds of audio at 16 kHz and automatically selects the strongest one-second speech region for classification.

---

## Hardware

### Required Hardware

- MoleNet V7.1 with ESP32-S3
- INMP441 I2S microphone
- USB cable

### INMP441 Wiring

| INMP441 | MoleNet V7.1 |
|---|---|
| VDD | 3.3 V |
| GND | GND |
| SCK / BCLK | GPIO40 |
| WS / LRCLK | GPIO41 |
| SD | GPIO42 |
| L/R | GND |

`L/R` is connected to GND, therefore the microphone is read from the left I2S channel.

The onboard action LED used in this experiment is:

```text
D6 -> GPIO38
```

---

## Project Structure

```text
TinyML_Keyword_Spotting/
|
├── README.md
|
└── firmware/
    ├── CMakeLists.txt
    ├── partitions.csv
    ├── sdkconfig.defaults
    ├── dependencies.lock
    |
    ├── components/
    │   └── kissfft/
    │       ├── CMakeLists.txt
    │       ├── kiss_fft.c
    │       ├── kiss_fft.h
    │       ├── kiss_fftr.c
    │       ├── kiss_fftr.h
    │       ├── _kiss_fft_guts.h
    │       ├── kiss_fft_log.h
            ├── COPYING.txt
    │       └── LICENSE
    |
    └── main/
        ├── CMakeLists.txt
        ├── idf_component.yml
        ├── main.cpp
        |
        ├── models/
        │   └── kws_3class.espdl
        |
        └── mfcc_params/
            ├── hann_window.bin
            ├── mel_filterbank_transposed.bin
            ├── dct_matrix.bin
            └── mfcc_params.txt
```

### Main Files

| File | Purpose |
|---|---|
| `main/main.cpp` | Audio capture, MFCC extraction, inference and LED control |
| `main/models/kws_3class.espdl` | Quantized keyword-spotting model |
| `main/mfcc_params/` | Parameters required for MFCC extraction |
| `main/idf_component.yml` | ESP-DL dependency |
| `components/kissfft/` | FFT implementation used for MFCC calculation |
| `partitions.csv` | Custom flash partition table |
| `sdkconfig.defaults` | Default ESP-IDF configuration |

---

# Build and Run

## 1. Install ESP-IDF

The experiment was tested with:

```text
ESP-IDF v6.0.2
Target: ESP32-S3
```

ESP-IDF installation:

https://docs.espressif.com/projects/esp-idf/en/release-v6.0/esp32s3/get-started/index.html

Windows setup:

https://docs.espressif.com/projects/esp-idf/en/stable/esp32/get-started/windows-setup.html

After installation, open an ESP-IDF terminal.

---

## 2. Open the Firmware Directory

From the MoleNet repository root:

```bash
cd experiments/TinyML_Keyword_Spotting/firmware
```

---

## 3. Set the ESP32-S3 Target

```bash
idf.py set-target esp32s3
```

---

## 4. Build the Firmware

```bash
idf.py build
```

ESP-DL is declared in:

```text
main/idf_component.yml
```

and is resolved by the ESP-IDF Component Manager during the build.

---

## 5. Connect the Board

Connect the MoleNet board to the computer using USB.

Identify the serial port.

Examples:

```text
Windows : COM34
Linux   : /dev/ttyUSB0
macOS   : /dev/cu.usbmodem...
```

---

## 6. Flash and Open the Serial Monitor

```bash
idf.py -p PORT flash monitor
```

Example:

```bash
idf.py -p COM34 flash monitor
```

Replace `PORT` with the port assigned to the board.

Exit the serial monitor with:

```text
Ctrl + ]
```

---

## 7. Test Keyword Recognition

Follow the prompt in the serial monitor and speak one of:

```text
YES
NO
UP
```

Expected LED behavior:

```text
YES -> D6 ON
NO  -> D6 OFF
UP  -> D6 blinks 3 times
```

An LED action is performed when prediction confidence is at least:

```text
70%
```

---

# How the Firmware Works

## 1. Audio Capture

The INMP441 microphone is sampled using the ESP32-S3 I2S interface.

```text
Sample rate : 16 kHz
Capture time: 2 seconds
Samples     : 32000
```

---

## 2. Speech-Region Selection

The model expects one second of audio.

The firmware searches the two-second recording for the strongest speech region and selects a one-second segment:

```text
16000 samples
```

This allows the keyword to be spoken anywhere within the capture period.

---

## 3. Audio Quality Check

Before feature extraction, the selected audio is checked for:

- low signal level
- clipping
- excessive microphone input level

The firmware uses an RMS threshold to reject very quiet recordings and checks the fraction of samples close to full-scale amplitude.

---

## 4. MFCC Feature Extraction

The selected one-second audio segment is converted to MFCC features directly on the ESP32-S3.

Configuration:

```text
Sample rate : 16000 Hz
FFT size    : 1024
Window      : 800 samples
Window time : 50 ms
Hop         : 160 samples
Hop time    : 10 ms
Mel filters : 128
MFCCs       : 40
Frames      : 101
```

Final model input:

```text
40 x 101 MFCC
```

Processing:

```text
Audio
  |
  v
Hann window
  |
  v
1024-point FFT
  |
  v
Power spectrum
  |
  v
Mel filterbank
  |
  v
dB conversion
  |
  v
DCT
  |
  v
40 x 101 MFCC
```

The following preprocessing parameters are embedded into the firmware:

```text
hann_window.bin
mel_filterbank_transposed.bin
dct_matrix.bin
```

KISS FFT is used for the FFT computation.

---

## 5. Neural-Network Inference

The MFCC features are passed to the embedded ESP-DL model:

```text
main/models/kws_3class.espdl
```

Output classes:

```text
0 -> YES
1 -> NO
2 -> UP
```

The predicted class and confidence are printed in the serial monitor.

Predictions below the configured confidence threshold do not trigger the LED action.

---

# Keyword-Spotting Model

The deployed model is a lightweight convolutional neural network.

```text
Input: 1 x 40 x 101

Conv2D
1 -> 8
3 x 3

ReLU
MaxPool

Conv2D
8 -> 16
3 x 3

ReLU
MaxPool

Adaptive Average Pool

Flatten

Linear
16 -> 3

Output:
YES / NO / UP
```

Total trainable parameters:

```text
1,299
```

The deployment pipeline is:

```text
PyTorch FP32 model
        |
        v
ONNX
        |
        v
ESP-PPQ quantization
        |
        v
W8A8 INT8 model
        |
        v
ESP-DL .espdl
        |
        v
ESP32-S3
```

`W8A8` means:

```text
8-bit weights
8-bit activations
```

---

## Model Performance

| Model | Test Accuracy |
|---|---:|
| FP32 | 95.87% |
| INT8 | 93.67% |

INT8 per-class accuracy:

| Keyword | Accuracy |
|---|---:|
| YES | 95.94% |
| NO | 90.12% |
| UP | 94.82% |

Final ESP-DL model size:

```text
11,616 bytes
approximately 11.34 KiB
```

---

# Dataset

The model was developed using the following classes from **Google Speech Commands v0.02**:

```text
yes
no
up
```

Google Speech Commands:

https://www.tensorflow.org/datasets/catalog/speech_commands

Speech Commands paper:

https://arxiv.org/abs/1804.03209

---

# ESP-DL

ESP-DL is used for neural-network inference on the ESP32-S3.

The project dependency is defined in:

```text
main/idf_component.yml
```

ESP-DL:

https://github.com/espressif/esp-dl

Documentation:

https://docs.espressif.com/projects/esp-dl/en/latest/getting_started/readme.html

Quantization documentation:

https://docs.espressif.com/projects/esp-dl/en/latest/tutorials/how_to_quantize_model.html

---

# ESP-PPQ

ESP-PPQ is used to quantize the ONNX model for ESP-DL deployment.

https://github.com/espressif/esp-ppq

---

# KISS FFT

KISS FFT is used for the FFT stage of MFCC extraction.

Source:

https://github.com/mborgerding/kissfft

The required source files are included in:

```text
firmware/components/kissfft/
```

The original BSD-3-Clause license is retained in:

```text
firmware/components/kissfft/LICENSE
```

---

# Custom Partition Configuration

The firmware uses the custom partition table:

```text
partitions.csv
```

The corresponding configuration is defined in:

```text
sdkconfig.defaults
```

```ini
CONFIG_PARTITION_TABLE_CUSTOM=y
CONFIG_PARTITION_TABLE_CUSTOM_FILENAME="partitions.csv"
CONFIG_PARTITION_TABLE_FILENAME="partitions.csv"
```

---

# Troubleshooting

## No Microphone Signal

Check the wiring:

```text
VDD -> 3.3 V
GND -> GND
SCK -> GPIO40
WS  -> GPIO41
SD  -> GPIO42
L/R -> GND
```

---

## Input Level Too High

Speak at a normal volume or increase the distance between the speaker and microphone.

Strongly clipped audio can reduce recognition accuracy.

---

## ESP-DL Build Error

Run:

```bash
idf.py fullclean
idf.py set-target esp32s3
idf.py build
```

---

## Wrong Serial Port

Check the board's serial port and use:

```bash
idf.py -p PORT flash monitor
```

---

## Repeated Incorrect Prediction

Check:

- microphone wiring
- background noise
- microphone distance
- speech volume
- clipping
- correct `.espdl` model
- MFCC parameter files

---

# References

### ESP-IDF

https://docs.espressif.com/projects/esp-idf/en/release-v6.0/esp32s3/get-started/index.html

### ESP32-S3 I2S

https://docs.espressif.com/projects/esp-idf/en/latest/esp32s3/api-reference/peripherals/i2s.html

### ESP-DL

https://github.com/espressif/esp-dl

https://docs.espressif.com/projects/esp-dl/en/latest/getting_started/readme.html

### ESP-PPQ

https://github.com/espressif/esp-ppq

### ONNX

https://onnx.ai/

### PyTorch

https://pytorch.org/

### TorchAudio MFCC

https://docs.pytorch.org/audio/main/generated/torchaudio.transforms.MFCC

### Google Speech Commands

https://www.tensorflow.org/datasets/catalog/speech_commands

https://arxiv.org/abs/1804.03209

### INMP441

https://invensense.tdk.com/wp-content/uploads/2015/02/INMP441.pdf

### KISS FFT

https://github.com/mborgerding/kissfft

---

# License

Refer to the repository-level `LICENSE` for the project license.

KISS FFT is distributed under its original BSD-3-Clause license:

```text
firmware/components/kissfft/LICENSE
```

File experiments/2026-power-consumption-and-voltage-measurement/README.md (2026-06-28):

Documentation is in [power consumption and voltage measurement.md](power consumption and voltage measurement.md). Pdf created with [MacDown3000](https://macdown.app/)'s export function.

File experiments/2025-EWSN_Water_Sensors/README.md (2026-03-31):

# Water Sensors

**Jens Dede, 2025** [jd@comnets.uni-bremen.de](mailto:jd@comnets.uni-bremen.de)

This repository contains the source code for the demo accompanying the paper:  
**"Slippery Signals: Investigating Sensor Crosstalk in Water Measurements"** *Published at EWSN 2025 in Leuven.*

---

## Overview

This project reads data from multiple sensors (electrical conductivity, dissolved oxygen, pH value) using a **MoleNet board** (with a custom adaptation board). The readings are transmitted via a serial connection to a desktop application that provides live updates.

### Objective
The primary goal is to demonstrate the effects of **duty cycling** on sensors: How are different sensors affected when placed simultaneously in a conductive liquid like water?

---

## Technical Details

This code has been tested on **MoleNet 6.3** using the MicroPython firmware:  
`ESP32_GENERIC_S3-20250911-v1.26.1.bin`

### Directory Structure

* `app/`: Contains the firmware logic. 
    * Upload the contents of `app/src` to the MoleNet board. 
    * It processes sensor data and outputs it as a JSON object to the serial line.
    * Includes additional convenience scripts for setup and testing.
* `readout/`: The PC-side application used to visualize the incoming data from the board.
* `2025-09-10_schematic.pdf`: The hardware schematic. 

> [!IMPORTANT]
> **Note on Hardware:** Two circuit versions exist with slightly different pinouts. If in doubt, please refer to the source code for the definitive pin assignments.

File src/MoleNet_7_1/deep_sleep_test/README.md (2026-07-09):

# Deep Sleep Test

Minimal test to measure MoleNet v7.1 deep sleep current with the onboard RA-01SH / SX1262 LoRa module.

## Files to Upload

Upload these files to the board:

* `main.py`
* `SX1262.py`
* `LoRaWAN.py`
* `EU868.py`
* `config_OTAA.py`
* `cmac.py`

## Before Measurement

* Remove external sensors.
* Do not use the onboard BME280 in this test.
* Remove the SD card from J13.
* Remove the SD card jumper pins from J13, if used.
* Remove the LED jumper from J4 pins 1 and 2.
* Remove the jumper from J16.
* Keep the LoRa antenna connected.

## Board + LoRa Measurement

* Keep LoRa VDD / RA_VDD connected.
* Run `main.py`.
* Wait until the board enters deep sleep.
* Measure the stable current.

This gives the board + LoRa deep sleep current.

## Board Only Measurement

* Disconnect LoRa VDD / RA_VDD.
* Keep the J13 SD card removed.
* Keep the J13 SD card jumper pins removed, if used.
* Keep the J4 LED jumper removed.
* Keep the J16 jumper removed.
* Run `main.py`.
* Wait until the board enters deep sleep.
* Measure the stable current.

This gives the board only deep sleep current.

## Notes

* `sx.sleep()` puts the LoRa chip into sleep mode but does not remove LoRa supply current.
* To measure board only current, LoRa VDD / RA_VDD must be disconnected.
* For the lowest board only deep sleep current, remove J4, J13, J16, and disconnect LoRa VDD / RA_VDD.

## Expected Current

* ESP32-S3 deep sleep current: **~15–20 µA**
* SX1262 / RA-01SH sleep current: **~1–2 µA**
* Remaining board overhead: **~100 µA**
* Total measured board + LoRa module: **~0.12 mA = 120 µA**

Measured value with GPIO deep sleep holds disabled:

esp32.gpio_deep_sleep_hold(False)

* **~0.12 mA = 120 µA**

If GPIO deep sleep holds are enabled, the measured current is higher:

esp32.gpio_deep_sleep_hold(True)

* **~0.45 mA = 450 µA**

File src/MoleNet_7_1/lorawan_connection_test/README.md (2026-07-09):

# LoRaWAN Connection Test

This folder contains minimal LoRaWAN connection test scripts for the MoleNet v7.1 board with the onboard RA-01SH / SX1262 LoRa module.

## Setup Instructions

For the complete setup steps, follow [`MoleNet_v7_1_LoRaWAN_Setup.md`](MoleNet_v7_1_LoRaWAN_Setup.md).

The Markdown guide explains how to:

* connect the MoleNet v7.1 board to TTN
* create the TTN application and device
* create the required config file
* upload files using Thonny
* verify the payload in TTN Live Data

## Test Files

* `main_abp.py`
  LoRaWAN ABP connection test.

* `main_otaa.py`
  LoRaWAN OTAA connection test.

Both scripts send `hello` to TTN every 60 seconds.

## Required Files

Upload the selected test script as `main.py` together with the required library files from the `lib/` folder.

For ABP, use:

* `config_ABP.py`

For OTAA, use:

* `config_OTAA.py`

## Notes

* Use only one test script at a time.
* Keep the LoRa antenna connected.
* No sensors are required.
* These scripts only test LoRaWAN connection.

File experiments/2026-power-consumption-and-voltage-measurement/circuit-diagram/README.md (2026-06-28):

The [circuit](https://www.circuit-diagram.org/editor/c/992d119d5fc840f2873c6cd66751a448) ([png](circuit.png),[svg](circuit.svg)) was designed with the online tool [Circuit Diagram Editor](https://www.circuit-diagram.org/editor/) and afterwards edited with [affinity studio](https://www.affinity.studio/) ([af](circuit.af)). The final result is [this](../images/circuit.png):

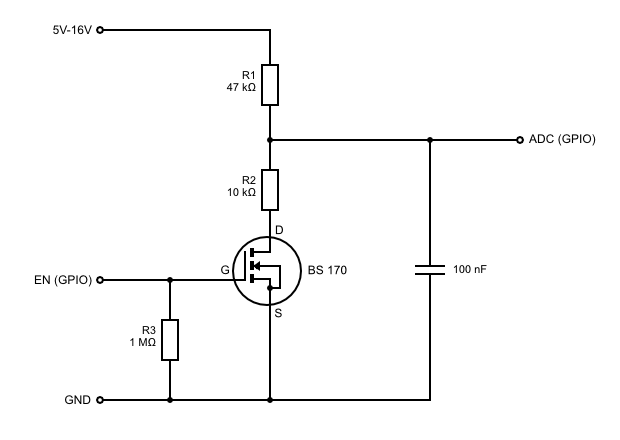
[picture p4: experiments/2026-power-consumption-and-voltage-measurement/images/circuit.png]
result


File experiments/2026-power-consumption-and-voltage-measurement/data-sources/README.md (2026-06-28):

Generates the graphs for the voltage drop over time.

Graphs are postprocessed with Pixelmator Pro to include the battery image in the top right corner. 

The python script [auswertenBK.py](auswertenBK.py) and [auswertenCN.py](auswertenCN.py) uses Pandas and Matpltlib, see requirements.txt, to generate the graphs from the datafiles [BKmoleNET-Data - data.csv](BKmoleNET-Data - data.csv) and [CNMoleNET-Data - data.csv](CNMoleNET-Data - data.csv).

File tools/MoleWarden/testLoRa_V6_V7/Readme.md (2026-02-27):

Test LoRa between V6 and V7
===========================
 
This folder contain the test files and libraries used for LoRa communication tests between V6 boards (SX1276 chip) and V7 boards (SX1262 chip).

The scripts contain infinite send or receive loops for V6 or V7 boards.

- snd_V6.py 
- rec_V6.py
- snd_V7.py
- rec_V7.py

copy the files to board and run them - for example - by typing 

```
import snd_v6
````

from the Python REPL prompt on a V6 board.

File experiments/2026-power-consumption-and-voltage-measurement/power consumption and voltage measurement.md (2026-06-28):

# Molenet 6.3 power consumption and voltage measurement

Alexander Förster (2026-06-28)

## Setup

All measurements are carried out with the Bad Kissingen setup. 

**Activated sensors**

- TEROS 11 soil moisture and temp sensor (external)
- DS18B20 temp sensor (external)
- BME280 temp, humidity, and air pressure sensor (internal)

**Other components**

The SD card was not connected or used in the power consumption setup, but later in the second battery run experiment. 

The LoRa module was connected adn used in both experiments. 

**Power**

Battery pack 6 x AA alkaline (not fresh)

## Power consumption measurement

The power consumption was measured manually with a benchtop multimeter multiple times over a test cycle. 

mode            | mean U | mean I  | max I  | mean t    
----            | -------| ------  | -----  | ------
active with LED | 8.30V  | 56mA    | 160mA  | 13sec 
active w/o LED  | 8.32V  | 50mA    | 154mA  | 12.7sec
sleep           | 8.43V  | 0.105mA | 0.11mA | 60sec

The LED switches on after 1-2 sec when active.   

Max is probably while sending LoRa packets. Exact measurements are required.

### How long does it run when it's updated every minute?

Two states:

- sleep 0.1mA for 60s
- active 50mA for 13s

Average: 
- (13s * 50mA + 60s * 0.1mA / 73s) = 8.8mA

Battery capacity: 
- approximately 2000mAh

Runtime:
- 2000mAh/8.8mA ~ 227h ~ 9 days
 
### How long does it run with one measurement each hour?

Two states:

- sleep 0.1mA for 3600s
- active 50mA for 13s

Average: 
- (13s * 50mA + 3600s * 0.1mA) / 3613s = 0.28mA

Battery capacity: 
- approximately 2000mAh

Runtime:
- 2000mAh/0.28mA ~ 7143h ~ 297 days

## Voltage measurement

### The circuit

The schematics of the circuit are drawn in the next image. R1 and R2 are a voltage divider for the battery voltage to convert it to the input voltage range of the ESP32. ADC should be connected to the ADC pin of the ESP32. EN should be connected to a digital output pin of the ESP32. 5V-16V should be connected to the battery and GND to the common ground of the battery and ESP32.

The BS 170 is an n-type MOSFET. Not the best choice but available at the lab. The 100nF capacitor is for reducing noise in the measurement and the resistor R3 is for pulling the gate to ground when the EN pin is open.  
   
circuit schematics

### Voltage divider

To find the best values for the resistors, we tested various combinations of resistors. 

The input voltage (battery) should be in the range of 16 V (fully charged lead acid battery) down to 3.5 V when the ESP32 will stop working.

The ESP32 can read voltages up to 3.3 V and will not be destroyed with voltages up to 3.6 V, but the linear range of measurements is between 0.15 V and 2.45 V.    

R1 value (real) | R2 value (real)   | stddev^(*) | dangerous Voltage | limit Voltage | linear min Voltage | linear max Voltage
---- | ----- | ------ |---- | ----| ---- | ---- | 
470k | 220k | not tested | 
220k (226.0k) | 100k (098.4k) | 0.1 | 11.9 V | 10.9 V | 0.495 V | 8.08 V
47k (47.070k) | 10k (9.920k) | 0.02 | 20.6 V | 18.9 V | 0.862 V | 14.1 V
22k (21.95k) | 10k (9.92k) | 0.01 | 11.6V | 10.6V | 0.482V | 7.87V
2.2k | 1k    | 0.01 (a bit better) |
 
^(*) standard deviation of 10 measurements, 2ms between each measurement. Measured 5V via USB and 9V via battery pack. Lower values mean less noise.   

We are using R1 = 47k and R2 = 10k for our measurements.

### Calibration

For R1 and R2, you can use 1% or 5% resistors. However, measure the real resistance and put these values in the software as constants to calculate realistic battery voltage values from the analog readings of the ESP32 (see below).   

### Molenet board

The following picture shows the Molenet board with the connected sensors. 

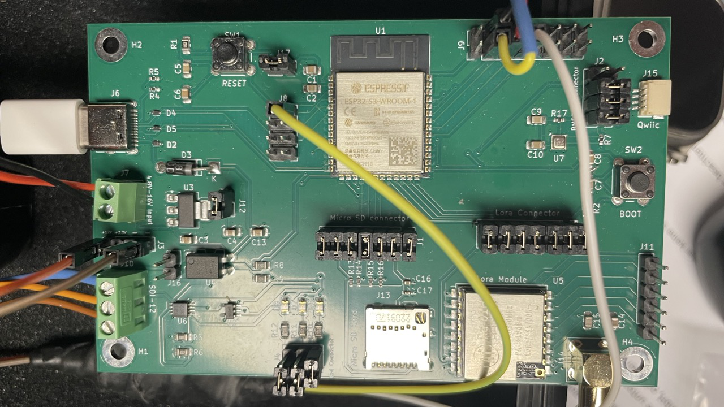
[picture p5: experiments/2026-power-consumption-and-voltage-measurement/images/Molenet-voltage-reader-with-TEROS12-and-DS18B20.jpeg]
Molenet board

### Software

The software is using pin 42 or 40 as the enable pin, pin 4 for analog readings. The values of R1 and R2 are set in Ohm. The program [main_battery_voltage.py](programs/main_battery_voltage.py) is for testing the voltage measurement, and the program [main.py](programs/main.py) is the standard test program for the Molenet node with TEROS12 and DS18B20 sensor.    

Here are the configutation parts fot the voltage measurement:

**Except from `main_battery_voltage.py`**

```python
# --- Voltage Divider Pin Configuration and Update Time ---
MEAS_EN_PIN = 42    # controls MOSFET
ADC_PIN = 4         # measures voltage # Attention:  Not all PINS are valid for ADC!
SLEEP_TIME_MS = 60 * 60 * 1000  # 1 hour

# --- Resistor Setup and  Voltage Divider Factor Calculation ---
R1 = 47_070 # in ohms. Here 47.070kOhm for a 47k resistor.
R2 =  9_920 # in ohms. Here 09.920kOhm for a 10k resistor.
DIVIDER_FACTOR = (R1 + R2) / R2

# --- ADC Setup ---
adc = ADC(ADC_PIN) 
adc.atten(ADC.ATTN_11DB)  # up to ~3.3V, 3.6V is absolute maximum, 
                          # the linear range is between 150mV and 2450mV 
                          # when read with read_uv().
adc.width(ADC.WIDTH_12BIT)  

```

**Exept from `main.py`**

```python
        # --- Resistor Setup and  Voltage Divider Factor Calculation ---
        self.vr_R1 = 47_070 # in ohms. Here 47.070kOhm for a 47k resistor.
        self.vr_R2 =  9_920 # in ohms. Here 09.920kOhm for a 10k resistor.
        self.vr_DIVIDER_FACTOR = (self.vr_R1 + self.vr_R2) / self.vr_R2

        # --- ADC Setup ---
        self.vr_adc = ADC(4)  # measures voltage # Attention:  Not all PINS are valid for ADC!
        self.vr_adc.atten(ADC.ATTN_11DB)  # up to ~3.3V, 3.6V is absolute maximum, 
                                          # the linear range is between 150mV and 2450mV 
                                          # when read with read_uv().
        self.vr_adc.width(ADC.WIDTH_12BIT) #  
        
        self.vr_meas_en = Pin(40, Pin.IN)  # OFF (high impedance!) controls gate to MOSFET
``` 
 
## Real experiment

However, tests from [Akkuline](https://www.akkuline.de/test/mignon-batterie-vergleich) have shown that the capacities of alkaline batteries are varying depending on the brand and type. Also, the official capacity in the data sheet is normally not the same as the one measured by an independent third party. For example, the VARTA HIGH ENERGY should have a capacity of 2264 mAh with a 250 mA load on the [data sheet](30011_VARTA_LONGLIFE_Power_AA_Datenblatt.pdf), but 1383 mAh with a 500 mA tested by [akkuline](https://www.akkuline.de/test-varta-high-energy-04906-aa-modell-2015-test-00171) when reaching 0.9 V. 

For this experiment, we used an older TEROS 12 sensor instead of a newer TEROS 11 sensor. 

Additionally, we used an additional circuit for on-board voltage measurement to estimate the battery's least capacity.

The next image shows the discharge profile from a "Duracel Basic" AA size battery from its [Data Sheet](https://cdn.prod.website-files.com/6835fa821f0f20d8b0b5851c/6899c928dedf627481a386e2_AA-Duracell.pdf). The profile depends strongly on the current (left) and on the temperture (right). All our measurements are taken at room temperatur. 

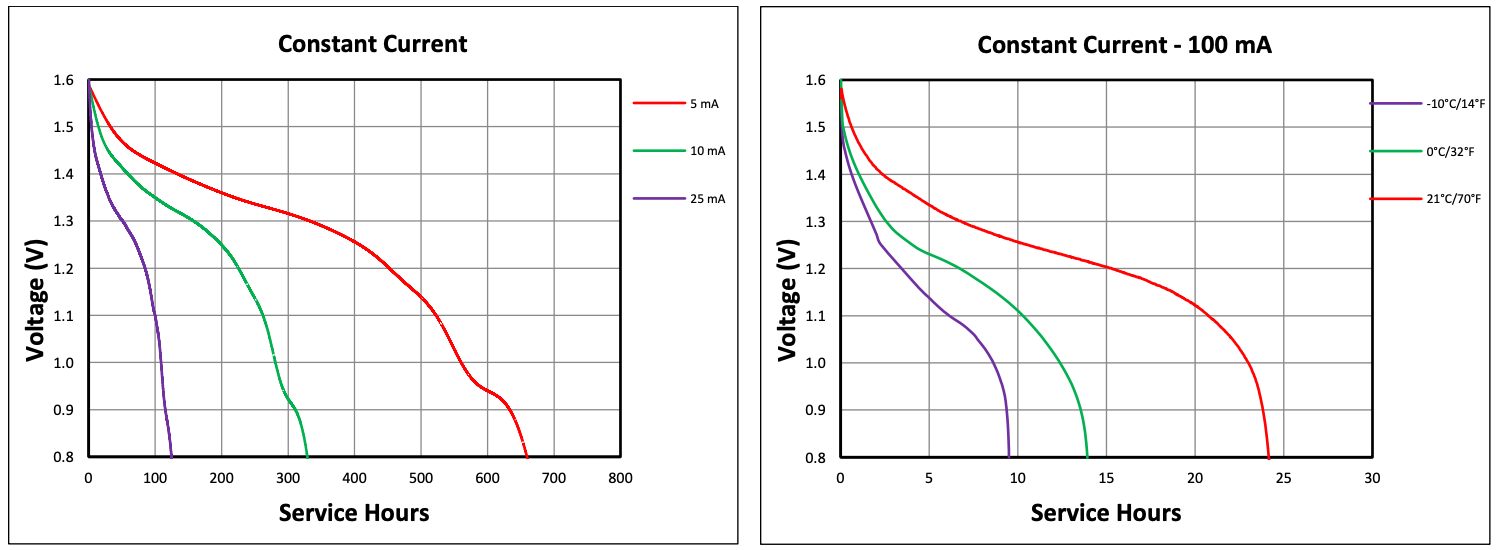
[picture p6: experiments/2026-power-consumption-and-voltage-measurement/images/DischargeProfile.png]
Discharge profile


The next image shows the first run with "Active Energy Super Alkaline" (ALDI brand) batteries. Runtime was around 6 days with not-fresh batteries. 

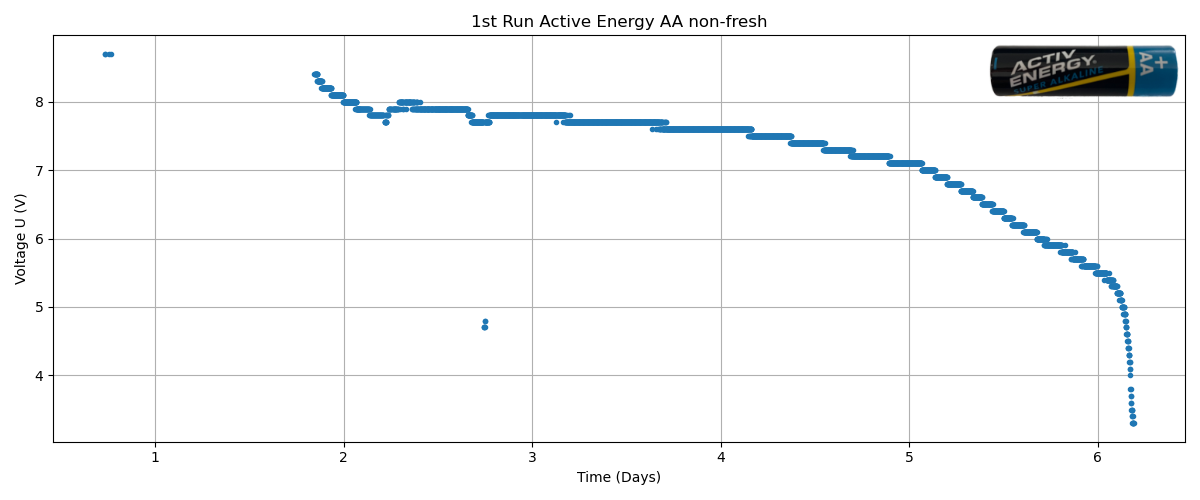
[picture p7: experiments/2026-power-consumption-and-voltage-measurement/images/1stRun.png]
1st run discharge measurement


The next image shows the second run with "VARTA longlife" batteries. Fresh batteries, but a SD-card was used to record the communication of the not-so-well-working TEROS 12 sensor for later analysis. Runtime around 11 days.  

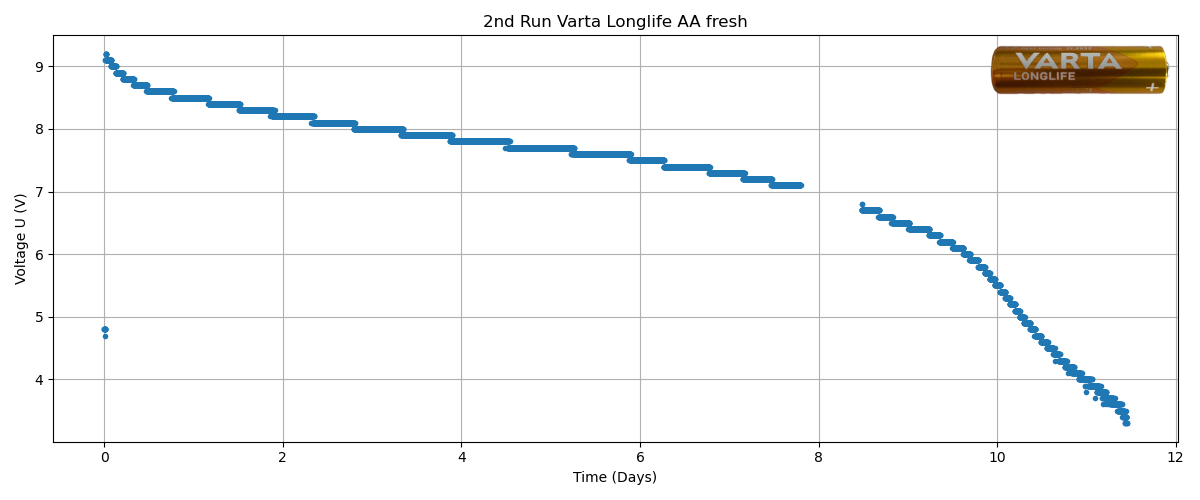
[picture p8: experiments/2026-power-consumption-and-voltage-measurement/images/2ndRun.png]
2nd run discharge measurement

  
## ToDo

**Power consuption**

- Measure the power consumption of the different parts of the boards separately (sensors, communication, MCU).   
- Run with various new/fresh batteries. Maybe also lithium batteries and lead acid batteries. 

**Voltage measurement**

- Calibration with real voltmeter?
- Response curve measurement for individual ESP32?
- Replacing the BS170 with a logic level MOSFET which is completely open with 3.3V on the gate. E.g. AO3400A (first) or BSS138 (second); both are only available as SMD components. ZVN2106A (first) or 2N7000 (second); Both are available as THT componets. 
- Drawings (schematics) of the connections on the Molenet board.

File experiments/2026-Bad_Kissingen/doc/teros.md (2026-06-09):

TEROS setup
===========

The TEROS ground soil sensor has to be configured when new. 
We can use the program `main_sdi12_terminal.py`, which is on the node, to setup the sensor.
We have to type some command strings which can be found in the user manual (TEROS 11/12 INTEGRATOR GUIDE).

~~~terminal
MPY: soft reboot
Init SDI12
16
SPI working, version check passed
Read config
SDI12> 0I!   # The default ID is 0, but the sensor behaves differently with id 0.
writing
reading
b'013METER   TER11 303T11-00044991\r\n'
SDI12> 0A1!  # Set another ID, for example 1, when we have only one SDI12 sensor on the node. 
writing
reading
b'1\r\n'
SDI12> 1I!   # Check if the sensor is reachable under it's new ID 1.
writing
reading
b'113METER   TER11 303T11-00044991\r\n'
SDI12> 
~~~

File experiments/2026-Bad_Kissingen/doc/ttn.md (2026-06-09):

Setup an new or old device for TTN
==================================

Activation
----------

See (End Device Activation)[https://www.thethingsnetwork.org/docs/lorawan/end-device-activation/] in (The Things Network)[https://www.thethingsnetwork.org/].

### OTAA (Over the air activation)

See Appendix A of Danil Helms' masterthesis `Masterthesis_LoRaWAN-Stack_Helms_Daniel_4224385.pdf`.

### ABP (Activation By Personalization)

See MoleNet v7.1 LoRaWAN Setup `MoleNet v7.1 LoRaWAN Setup.pdf`.

When somethig does not work
---------------------------

When you see the message "Ups, i have to join to LoRWAN (OTAA) again?"

```sh
    activate # activate python venv in the directory where you find pyboard.py
    python pyboard.py -d /dev/tty.usbmodem* -f ls # Does .confog.cfg exist?
    python pyboard.py -d /dev/tty.usbmodem* -f rm .config.cfg  # delete it
    python pyboard.py -d /dev/tty.usbmodem* -f ls # Was it removed?
```

check the parameters in lib/config_OTAA.py!

When the device has moved to another Application: change the AppKey to the AppKey of the new application

Register Webhooks
-----------------

1. Go to webhooks on the application in ttn. 
2. select "+Add Webhook"
3. select "Custom Webhook"
4. Fill out som parameters in the form:
- Webhook ID: google-sheets
- Base URL: the Apps Script /exec URL from the Google Docs Extensions "Apps Script" Deploy action.
- Uplink message: Enable the select box but leave the text field empty

See also Part C in MoleNet v7.1 LoRaWAN Setup `LoRaWAN/MoleNet v7.1 LoRaWAN Setup.pdf` on page 5ff.

When something went wrong ttn does not help with finding the error. The first step is to use 'Postman'. Try on Postman to send a 'Post' message with

https://script.google.com/macros/s/AKfycbwxn_xvh74p6UPbFNSucKHgF2fEvTc__FJs00v9doGHmX6J3kDd0usndNf7NtM3uwMi/exec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{"device_id":"my device"} 

When you get an error 403 Forbidden go to the Google Apps Script and select Deploy/Test deployment. Call the url in a separate window and give access to the data. Now Postman should work with a get (info message) and as well a post method (probably status error because the JSON content is not correct).

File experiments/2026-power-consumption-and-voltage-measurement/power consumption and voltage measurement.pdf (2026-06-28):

Alexander Förster (2026-06-28)

All measurements are carried out with the Bad Kissingen setup.

Activated sensors

TEROS 11 soil moisture and temp sensor (external) DS18B20 temp sensor (external)
BME280 temp, humidity, and air pressure sensor (internal)

Other components

The SD card was not connected or used in the power consumption setup, but later in the second battery run experiment.

The LoRa module was connected adn used in both experiments.

Power

Battery pack 6 x AA alkaline (not fresh)

The power consumption was measured manually with a benchtop multimeter multiple times over a test cycle.

# Molenet 6.3 power consumption and voltage measurement

# Setup

# Power consumption measurement

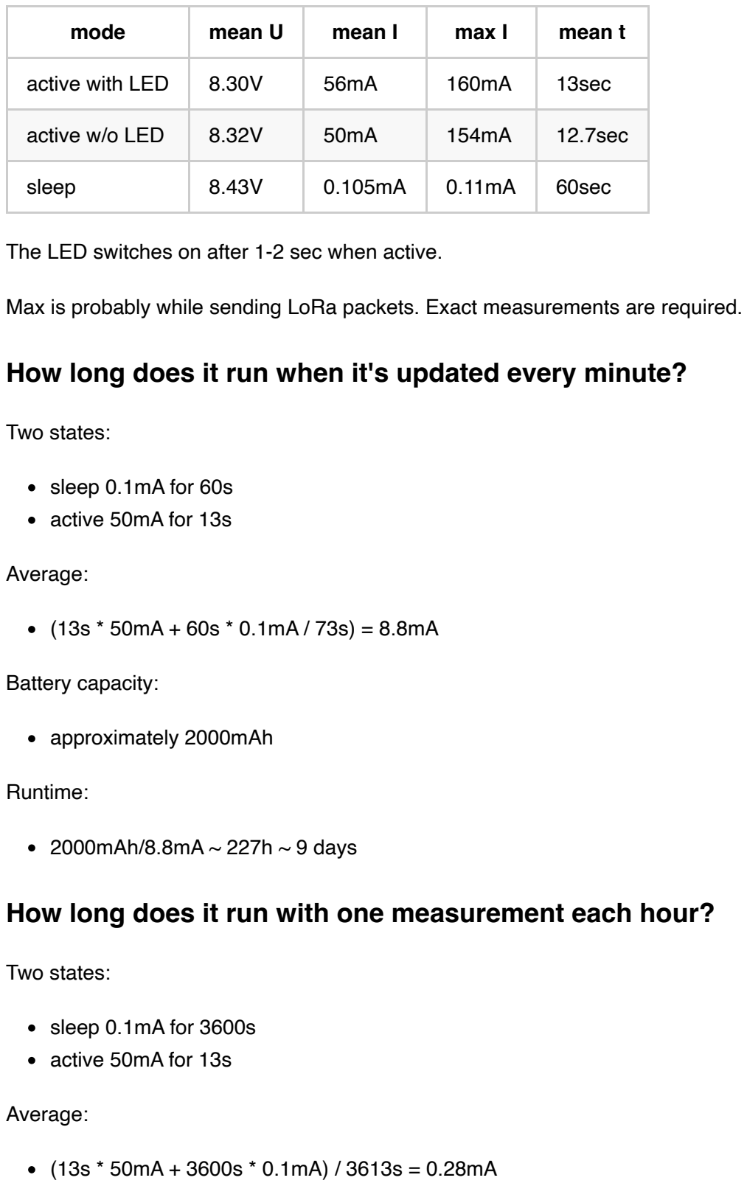
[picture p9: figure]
mode; mean U; mean I; max I; mean t; active with LED; 13sec; active w/o LED; 12.7sec; sleep; 60sec; Two states:; sleep 0.1mA for 60s; active 50mA for 13s; Average:; Battery capacity:; approximately 2000mAh; Runtime:; 2000mAh/8.8mA ~ 227h ~ 9 days; sleep 0.1mA for 3600s

The LED switches on after 1-2 sec when active.

Max is probably while sending LoRa packets. Exact measurements are required.

(13s * 50mA + 60s * 0.1mA / 73s) = 8.8mA

(13s * 50mA + 3600s * 0.1mA) / 3613s = 0.28mA

## How long does it run when it's updated every minute?

## How long does it run with one measurement each hour?

Battery capacity:

approximately 2000mAh

Runtime:

2000mAh/0.28mA ~ 7143h ~ 297 days

The schematics of the circuit are drawn in the next image. R1 and R2 are a voltage divider for the battery voltage to convert it to the input voltage range of the ESP32. ADC should be connected to the ADC pin of the ESP32. EN should be connected to a digital output pin of the ESP32. 5V-16V should be connected to the battery and GND to the common ground of the battery and ESP32.

The BS 170 is an n-type MOSFET. Not the best choice but available at the lab. The 100nF capacitor is for reducing noise in the measurement and the resistor R3 is for pulling the gate to ground when the EN pin is open.

# Voltage measurement

## The circuit

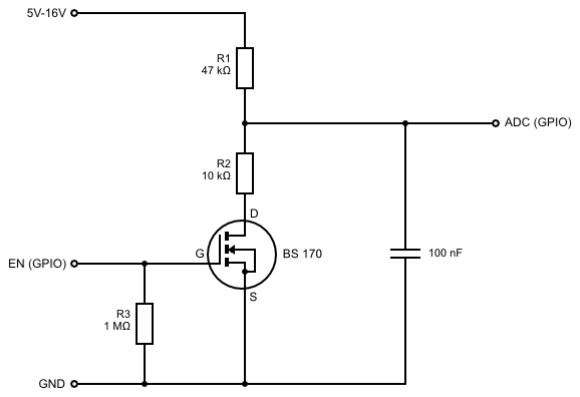
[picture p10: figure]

To find the best values for the resistors, we tested various combinations of resistors.

The input voltage (battery) should be in the range of 16 V (fully charged lead acid battery) down to 3.5 V when the ESP32 will stop working.

The ESP32 can read voltages up to 3.3 V and will not be destroyed with voltages up to 3.6 V, but the linear range of measurements is between 0.15 V and 2.45 V.

## Voltage divider

R1 value (real) | R2 value (real) | stddev* | dangero us Voltage | limit Volta ge | linear min Voltage | linear max Voltage
470k | 220k | not tested
220k (226.0 k) | 100k (098.4 k) | 0.1 | 11.9 V | 10.9 V | 0.495 V | 8.08 V
47k (47.07 0k) | 10k (9.920 k) | 0.02 | 20.6 V | 18.9 V | 0.862 V | 14.1 V
22k (21.95 k) | 10k (9.92k) | 0.01 | 11.6V | 10.6V | 0.482V | 7.87V
2.2k | 1k | 0.01 (a bit better)

*
standard deviation of 10 measurements, 2ms between each measurement. Measured 5V via USB and 9V via battery pack. Lower values mean less noise.

We are using R1 = 47k and R2 = 10k for our measurements.

For R1 and R2, you can use 1% or 5% resistors. However, measure the real resistance and put these values in the software as constants to calculate realistic battery voltage values from the analog readings of the ESP32 (see below).

The following picture shows the Molenet board with the connected sensors.

## Calibration

## Molenet board

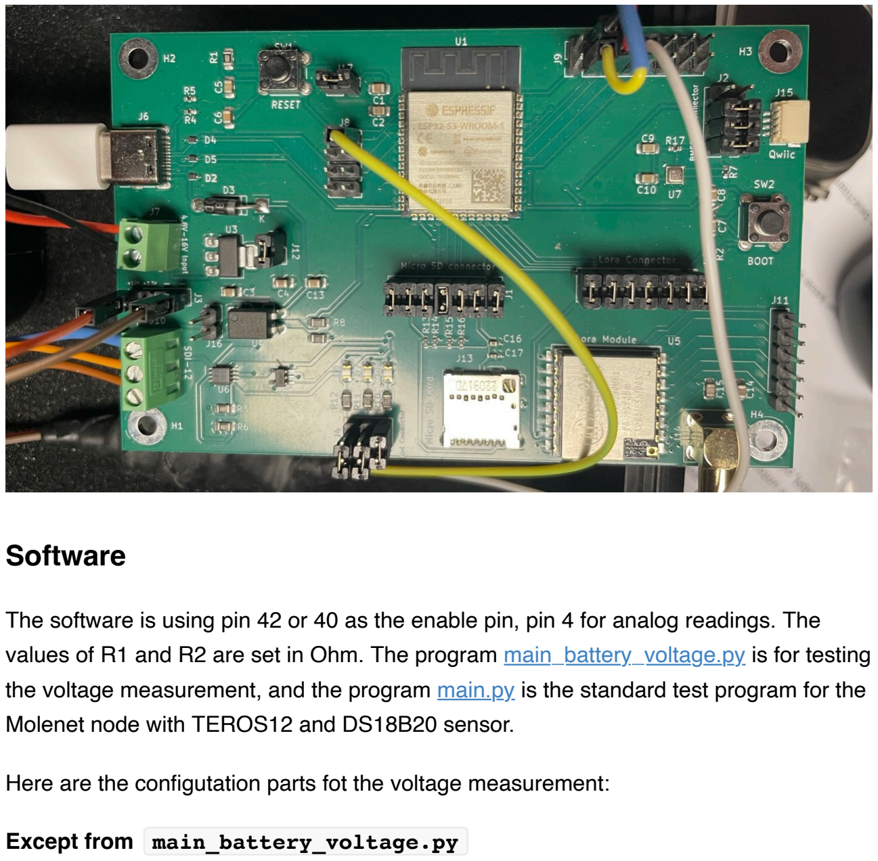
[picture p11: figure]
Except from main_battery_voltage.py; Software

The software is using pin 42 or 40 as the enable pin, pin 4 for analog readings. The values of R1 and R2 are set in Ohm. The program main_battery_voltage.py is for testing the voltage measurement, and the program main.py is the standard test program for the Molenet node with TEROS12 and DS18B20 sensor.

Here are the configutation parts fot the voltage measurement:

# --- Voltage Divider Pin Configuration and Update Time ---

MEAS_EN_PIN | = | 42 | # controls MOSFET
ADC_PIN | = | 4 | # measures voltage # Attention: Not all PINS are
valid for ADC!
SLEEP_TIME_MS | = | 60 | * | 60 | * | 1000 # 1 hour

# --- Resistor Setup and Voltage Divider Factor Calculation ---

R1 | = | 47_070 # in ohms. Here 47.070kOhm for a 47k resistor.
R2 | = | 9_920 # in ohms. Here 09.920kOhm for a 10k resistor.
DIVIDER_FACTOR | = | (R1 | + | R2) | / | R2

# --- ADC Setup ---

adc | = | ADC(ADC_PIN)
adc.atten(ADC.ATTN_11DB) # up to ~3.3V, 3.6V is absolute maximum, # the linear range is between 150mV and 2450mV # when read with read_uv(). adc.width(ADC.WIDTH_12BIT)

Exept from main.py

# --- Resistor Setup and Voltage Divider Factor Calculation ---

self.vr_R1 | = | 47_070 # in ohms. Here 47.070kOhm for a 47k
resistor.
self.vr_R2 | = | 9_920 # in ohms. Here 09.920kOhm for a 10k
resistor.
self.vr_DIVIDER_FACTOR | = | (self.vr_R1 | + | self.vr_R2) | / | self.vr_R2

# --- ADC Setup ---

self.vr_adc | = | ADC(4) # measures voltage # Attention: Not all
PINS are valid for ADC!
self.vr_adc.atten(ADC.ATTN_11DB) # up to ~3.3V, 3.6V is absolute maximum,
# the linear range is between 150mV and 2450mV

# when read with read_uv(). self.vr_adc.width(ADC.WIDTH_12BIT) #

self.vr_meas_en | = | Pin(40, Pin.IN) # OFF (high impedance!)
controls gate to MOSFET

However, tests from Akkuline (https://www.akkuline.de/test/mignon-batterie-vergleich) have shown that the capacities of alkaline batteries are varying depending on the brand and type. Also, the official capacity in the data sheet is normally not the same as the one measured by an independent third party. For example, the VARTA HIGH ENERGY should have a capacity of 2264 mAh with a 250 mA load on the data sheet, but 1383 mAh with a 500 mA tested by akkuline (https://www.akkuline.de/test-varta-high-energy-04906-aa-modell-2015-test-00171) when reaching 0.9 V.

For this experiment, we used an older TEROS 12 sensor instead of a newer TEROS 11 sensor.

Additionally, we used an additional circuit for on-board voltage measurement to estimate the battery's least capacity.

The next image shows the discharge profile from a "Duracel Basic" AA size battery from its Data Sheet. (https://cdn.prod.website-files.com/6835fa821f0f20d8b0b5851c/6899c928dedf627481a386e2_AA-Duracell.pdf) The profile depends strongly on the current (left) and on the temperture (right). All our measurements are taken at room temperatur.

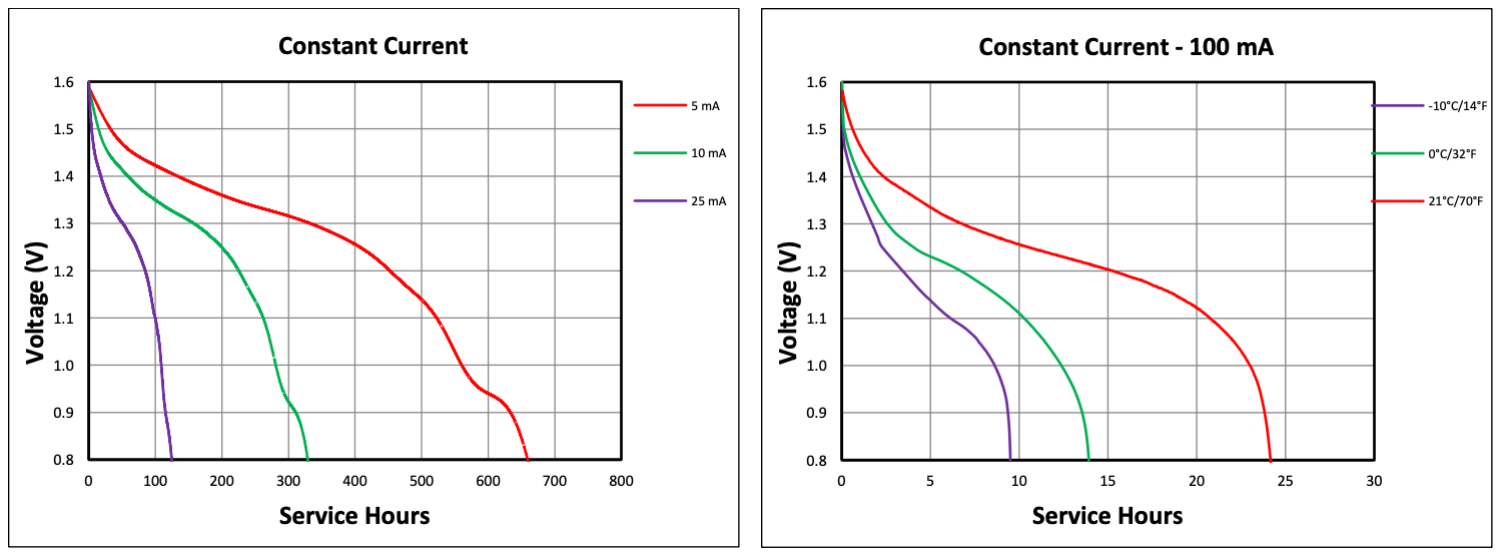
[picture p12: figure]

The next image shows the first run with "Active Energy Super Alkaline" (ALDI brand) batteries. Runtime was around 6 days with not-fresh batteries.

# Real experiment

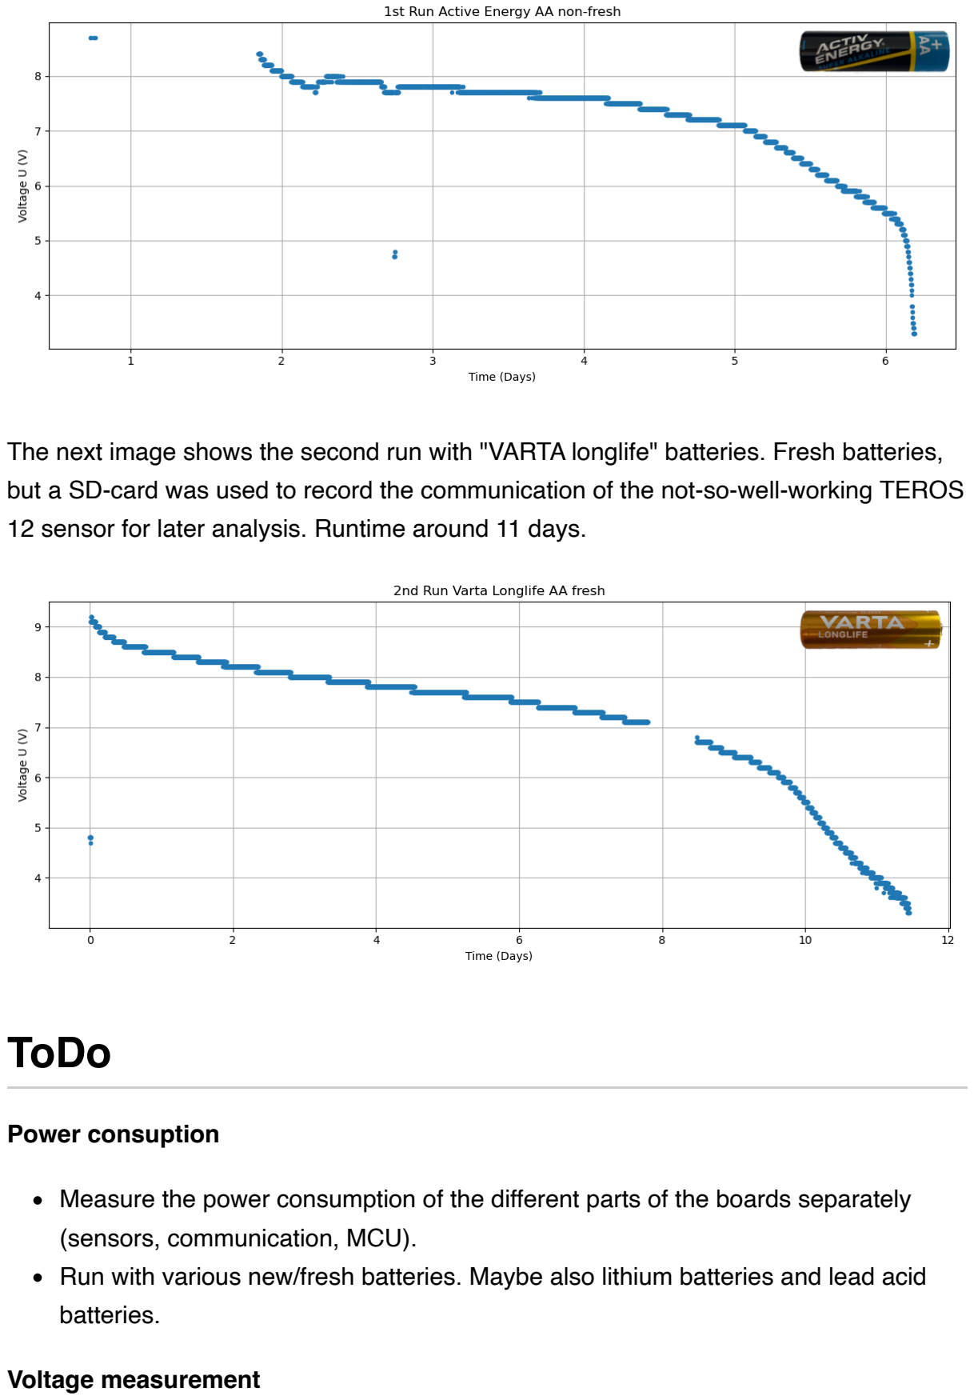
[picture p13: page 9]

The next image shows the second run with "VARTA longlife" batteries. Fresh batteries, but a SD-card was used to record the communication of the not-so-well-working TEROS 12 sensor for later analysis. Runtime around 11 days.

Power consuption

Measure the power consumption of the different parts of the boards separately (sensors, communication, MCU).
Run with various new/fresh batteries. Maybe also lithium batteries and lead acid batteries.

Voltage measurement

# ToDo

Calibration with real voltmeter?
Response curve measurement for individual ESP32?
Replacing the BS170 with a logic level MOSFET which is completely open with 3.3V on the gate. E.g. AO3400A (first) or BSS138 (second); both are only available as SMD components. ZVN2106A (first) or 2N7000 (second); Both are available as THT componets.
Drawings (schematics) of the connections on the Molenet board.

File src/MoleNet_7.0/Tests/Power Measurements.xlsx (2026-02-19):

Device=Molenet V7.0 | Idle | Lightsleep | Deepsleep | Note
Molenet Board | 30.4 mA | 0.94 mA | 128 uA
Molenet Board+LoRa | 31.2 mA | 1.8 mA | 0.69 mA
Molenet Board+LoRa+SD Card | 31.2 mA | 1.8 mA | 0.69 mA | No Read and write operation. It needs to be checked additionally
Molenet Board+LoRa+SD Card+BME280 | 31.2 mA | 1.8 mA | 0.69 mA | No data requested from BME
Molenet Board+LoRa+SD Card+BME280+LEDS | 37.7 mA | 8.3 mA | 7.2 mA
Device=Molenet V6.3 | Idle | Lightsleep | Deepsleep | Note
Molenet Board | 32 mA | 1.4 mA | 140uA
Molenet Board+LoRa | 35 mA | 3.9 mA | 2.5 mA
Molenet Board+LoRa+SD Card | 35 mA | 3.9 mA | 2.5 mA | No Read and write operation. It needs to be checked additionally
Molenet Board+LoRa+SD Card+BME280 | 35 mA | 3.9 mA | 2.5 mA | No data requested from BME
Molenet Board+LoRa+SD Card+BME280+LEDS | 41 mA | 10 mA | 8.7 mA
Device=Molenet V6.1 | Idle | Lightsleep | Deepsleep | Note
Molenet Board | 32 mA | 1 mA | 80 uA
Molenet Board+LoRa | 34 mA | 2.8 mA | 1.8 mA
Molenet Board+LoRa+SD Card | 34 mA | 2.8 mA | 1.8 mA | No Read and write operation. It needs to be checked additionally
Molenet Board+LoRa+SD Card+BME280 | 34 mA | 2.8 mA | 1.8 mA | No data requested from BME
Molenet Board+LoRa+SD Card+BME280+LEDS | 40 mA | 9.4 mA | 8.4 mA

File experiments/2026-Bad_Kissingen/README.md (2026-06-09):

# MoleNet in Bavaria

**Alexander Förster, 2026** [axf@uni-bremen.de](mailto:axf@uni-bremen.de)

We installed two MoleNet nodes in Bad Kissingen at the Zukunftslabor. 

---

## Overview

This Repository contains all the configuration data and source code for the nodes, the TNN application and google sheets as one example data sink. The data is also available at [grafana.comnets.uni-bremen.de/](https://grafana.comnets.uni-bremen.de/)

## Directories and Files

### TTN (The Things Network)

- `payload_formater.js`: converts the binary data received from the nodes via LoRaWan to a json data structure which will be forwarded to the sinks.

### Node (Molenet Node Python Code)

Contains all python files which are on the nodes. The `main.py` program and
the `src` directory are used regulary. All other programs can be used for special purporses. Maybe started from Thonny or screen. 

- `main.py`: The default program. Sends all sensor data via LoRaWan to TTN and sleeps deeply in between for 60 seconds to 60 minutes (last command).
- `main_sdi12_terminal.py`: Used to communicate directly with the TEROS11/12 sensor to change it's configuration or get additional information from the sensor.
- `main_reader.py`: Almost the same as `main.py`, but will not go to deep sleep. Instead, it stays connected an the sensor data can be read conmtinously from the Thonny terminal.
- `main_lorawan_test_and_register_otaa.py`: Has to be used for register the node on TTN with OTAA (Over The Air Activation) instead of ABP (Activation By Personalization).
- `boot.py`: The boot script (called after startup and deepsleep). Normally empty.
- `.config.cfg`: A hidden file created and managed by `lib/LoRaWAN.py`. Contains keys after activation with TTN. Must be deleted before a new activation.
- `lib/config_OTAA.py`: The `lib` directory contains libraries for the sensors. Additionally, the file `config_OTAA.py` contains configuration information. 

### Google

The data from the two MoleNet nodes is stored on a [grafana instance](https://grafana.comnets.uni-bremen.de/)) and in a [google sheet](https://docs.google.com/spreadsheets/d/1am54Mm_Peyzo58hMVs5cYSzmUhW6zH7aOMFH0EJhQ6s/edit?usp=sharing). To add new data received from TTN a Google Apps Script `Code.gs` is required as extension to the spreadsheet.

- `Code.gs`: The script receives a json data block from TTN and converts it into a new row in the spreadsheet.

### Doc

- `setup.md`:
- `ttn.md`: 
- `teros.md`: How to configure a new TEROS11/12 soil sensor.

## Additional Information for ComNets members

The ComNets [KnowledeBase](https://kb.comnets.uni-bremen.de/books/mainzaun/page/deployment-bad-kissingen) and [NextCloud](https://nc.uni-bremen.de/index.php/apps/files/files/154767326?dir=/Bad%20Kissingen) contains additional information.

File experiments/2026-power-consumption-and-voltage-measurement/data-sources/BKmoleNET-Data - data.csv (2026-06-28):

date and time (zulu, UTC) | device id | BME 280 |  |  | DS18B20 | TEROS 11/12 |  | TEROS 11/12 | TEROS 12 | Battery | raw data
 |  | humidity (%) | air pressure (hPa) | temp (°C) | temp (°C) | vwc (m^3/m^3) | temp (°C) | perm (raw) | econ (µS/cm) | U (V)
2026-04-22T16:42:05.927980547Z | igc-2025-06-14-otaa | 18.8 | 1,026 | 25.4 | 22.1 | 14.6% | 22.0
2026-04-22T16:43:19.025183065Z | igc-2025-06-14-otaa | 18.9 | 1,026 | 25.4 | 22.4 | 44.8% | 22.1
2026-04-22T16:44:32.201918630Z | igc-2025-06-14-otaa | 18.9 | 1,026 | 25.3 | 22.4 | 43.1% | 22.1
2026-04-22T16:45:45.427198110Z | igc-2025-06-14-otaa | 18.9 | 1,026 | 25.3 | 22.4 | 42.2% | 22.1
2026-04-22T16:46:58.701904302Z | igc-2025-06-14-otaa | 19.1 | 1,026 | 25.3 | 22.4 | 41.6% | 22.1
2026-04-22T16:48:12.022839073Z | igc-2025-06-14-otaa | 18.8 | 1,026 | 25.3 | 22.4 | 40.9% | 22.1
2026-04-22T16:49:25.429446407Z | igc-2025-06-14-otaa | 19.0 | 1,026 | 25.3 | 22.4 | 40.4% | 22.1
2026-04-22T16:50:38.805172574Z | igc-2025-06-14-otaa | 18.9 | 1,026 | 25.3 | 22.4 | 40.0% | 22.0
2026-04-22T16:51:52.223854809Z | igc-2025-06-14-otaa | 18.9 | 1,026 | 25.3 | 22.4 | 39.5% | 22.0
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

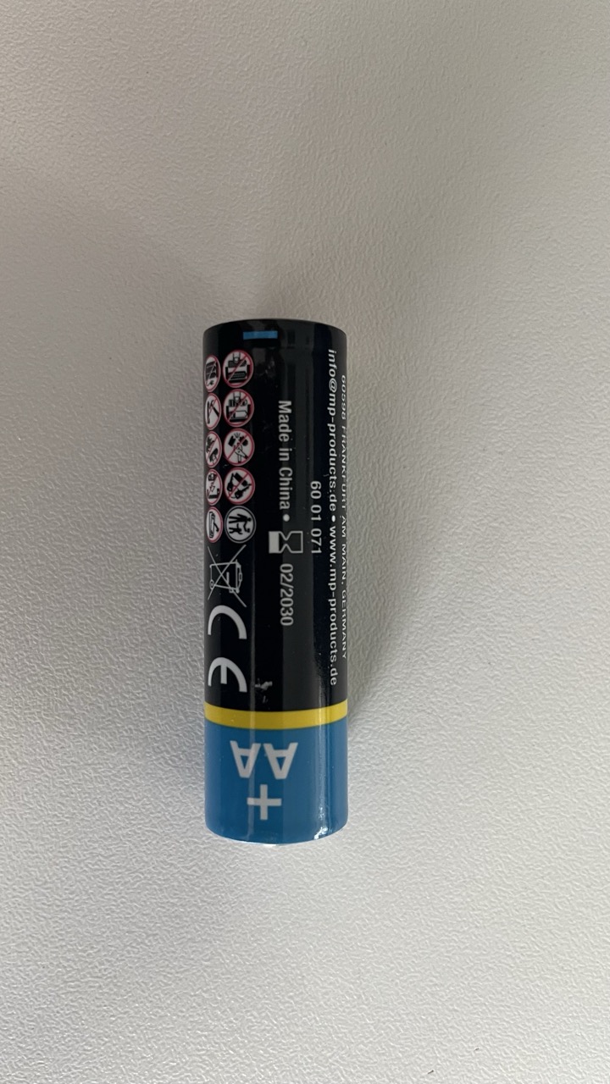
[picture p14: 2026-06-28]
experiments/2026-power-consumption-and-voltage-measurement/data-sources/battery-images/IMG_7202 Large.jpeg

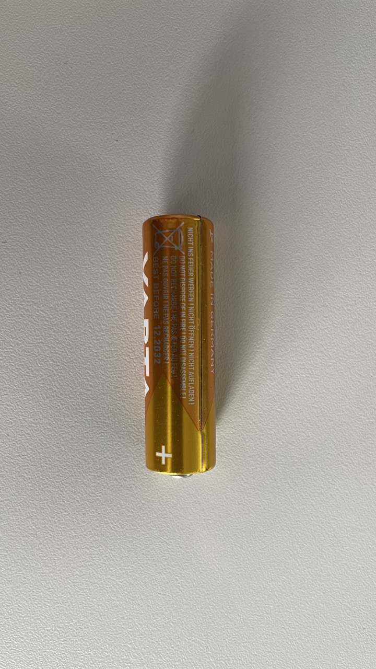
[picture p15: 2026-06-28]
experiments/2026-power-consumption-and-voltage-measurement/data-sources/battery-images/IMG_7205 Large.jpeg

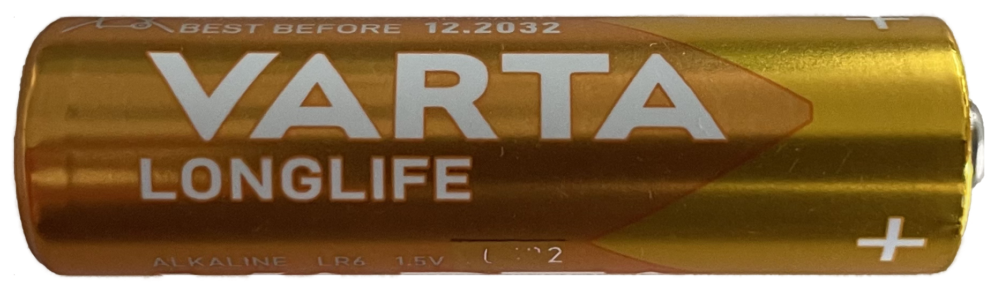
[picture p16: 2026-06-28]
experiments/2026-power-consumption-and-voltage-measurement/data-sources/varta-longlife.png

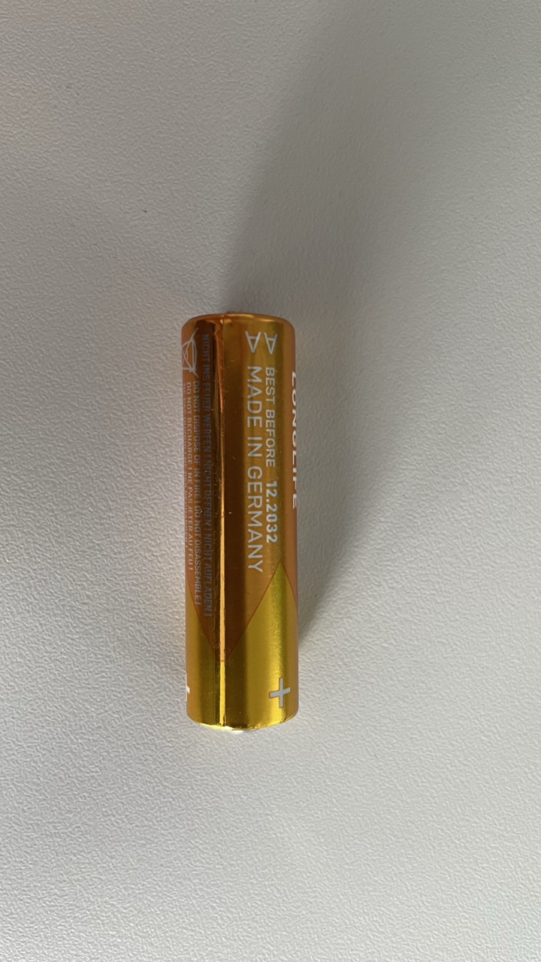
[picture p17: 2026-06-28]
experiments/2026-power-consumption-and-voltage-measurement/data-sources/battery-images/IMG_7204 Large.jpeg

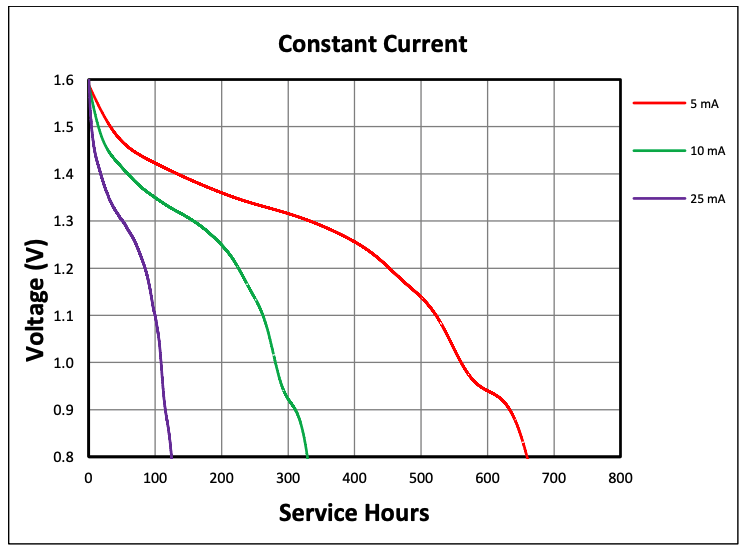
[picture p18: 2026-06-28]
experiments/2026-power-consumption-and-voltage-measurement/duracel-info/duracel-current.png

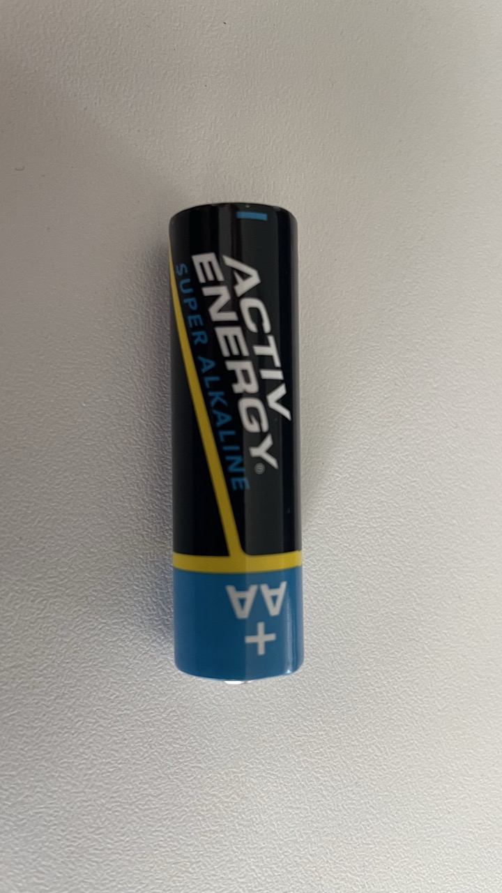
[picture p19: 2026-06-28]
experiments/2026-power-consumption-and-voltage-measurement/data-sources/battery-images/IMG_7200 Large.jpeg

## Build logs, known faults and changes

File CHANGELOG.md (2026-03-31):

# Changelog

## Hardware

The different layouts are located in the [PCB-Layouts](PCB-Layouts) directory.
Each directory (should) contain a `*_schematic.pdf` file with the corresponding
schematic.

### MoleNet v7.1

- Fixed the BUSY pin of the SX1262 from 45 - 39
- New protection circuit with p-channel MOSFET (IRLML5203). The old one with 1N5819 is available, but unpopulated
- Additional test scripts etc.

### MoleNet v7.0

- Inverter to the RX side added (BS170 mosfet)
- Antenna area of ESP increased
- Additional I2C pins added to the headers
- Headers re-organized for optimized connection to external boards. Added several power and GND pins
- Added 1N5819 protection diode to the input (reverse polarity)
- Input voltage labels corrected
- Lora module changed from RA-01H (SX1276 chip) to RA-01SH (SX1262 chip)

**Known issues**

- Not yet

### MoleNet v6.3

- Changed the LoRa reset pin to GPIO15: This one keeps the state during reset
  and therefore, keeps the LoRa module in sleep mode
- Add more logos at the back
- Improved the labels on the PCB

**Known issues**

- Not yet

### MoleNet v6.2

- Fixed the SDI-12 interface
- Fixed some labels (reset button, BME enable pins)
- Increase size of mounting holes from M2 to M3

**Known issues**

- Reset pin of LoRa not working. Bugfix: Keep the jumper for reset on J5 empty

### MoleNet v6.1

- Fixed the broken LED
- Add a QWIC connector for I2c-based devices
- Add an on-board BME280 temperature, humidity, ambient pressure sensor
- SD card power can be switched via a GPIO

### MoleNet v6.0

Redesign based on ESP32-S3, first version:

- The ESP supports MicroPython and Arduino
- All major components can be disconnected
- Direct ESP32 support for RTC
- SDI-12 interface, SD-card reader, native USB-port

**Known issues**

- Missing resistor on LED D7 (center)
- SDI-12 interface not working

### MoleNet v5.2.2

Change in USART interface, new HF connector

### MoleNet v5.2

Add more jumpers for the LEDs

### MoleNet v5.1

Minor improvements, add connections for jumpers to completely disconnect the
transceiver module

### MoleNet v5.0

Redesign with the STM32L073RZT6 and an on-board SD-card interface,
well-optimized to low power applications.

### MoleNet v3.0

A redesign now based on the ATMEGA1284P, using an on board analog battery monitor, an MCP7940M RTC, improved SDI-12 interface, power enable pins etc.
This version offers more computing capabilities compared to the previous ones.

### MoleNet v2.1

Minor improvements for the SDI-12 sensor interface

### MoleNet v2.0

This version has additional GPIO (analog and digital) available. Further, the
EEPROM access has been improved.

### MoleNet v1.0

First version of MoleNet. This version is based on an ATMEGA328P-PU and is
programmed using the Arduino IDE. Further, it has an RFM69VW radio transceiver,
an EEPROM, an SDI-12 sensor interface and a connector for an external RV8523 RTC
module.

## Software

TODO

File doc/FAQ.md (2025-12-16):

FAQ: Frequently Asked Questions
===============================

Here, we gather some common question that are frequently asked.

Where do you order you PCBs?
----------------------------

Right now, we order the fully equipped PCBs from [jlcpcb](https://jlcpcb.com/).

Why is the PCB that big?
------------------------

We have two reasons for the size:

1) As the focus is environmental monitoring with buried sensors, the size makes
it easier to find and recover them.
2) It is a student project. Larger size (and more connectors) makes it easier
to handle

Why do you use the ESP32-S3 version?
------------------------------------

The ESP32-S3 offers (in our opinion) a good trade-off between computing
capabilities even suitable for AI and low power. Further, it is supported by a wide range of embedded system frameworks / operating systems like Arduino, MicroPython, RiotOS, Zephyr, etc.

It can also be programmed by non-experts without additional hardware which is
essential for teaching.

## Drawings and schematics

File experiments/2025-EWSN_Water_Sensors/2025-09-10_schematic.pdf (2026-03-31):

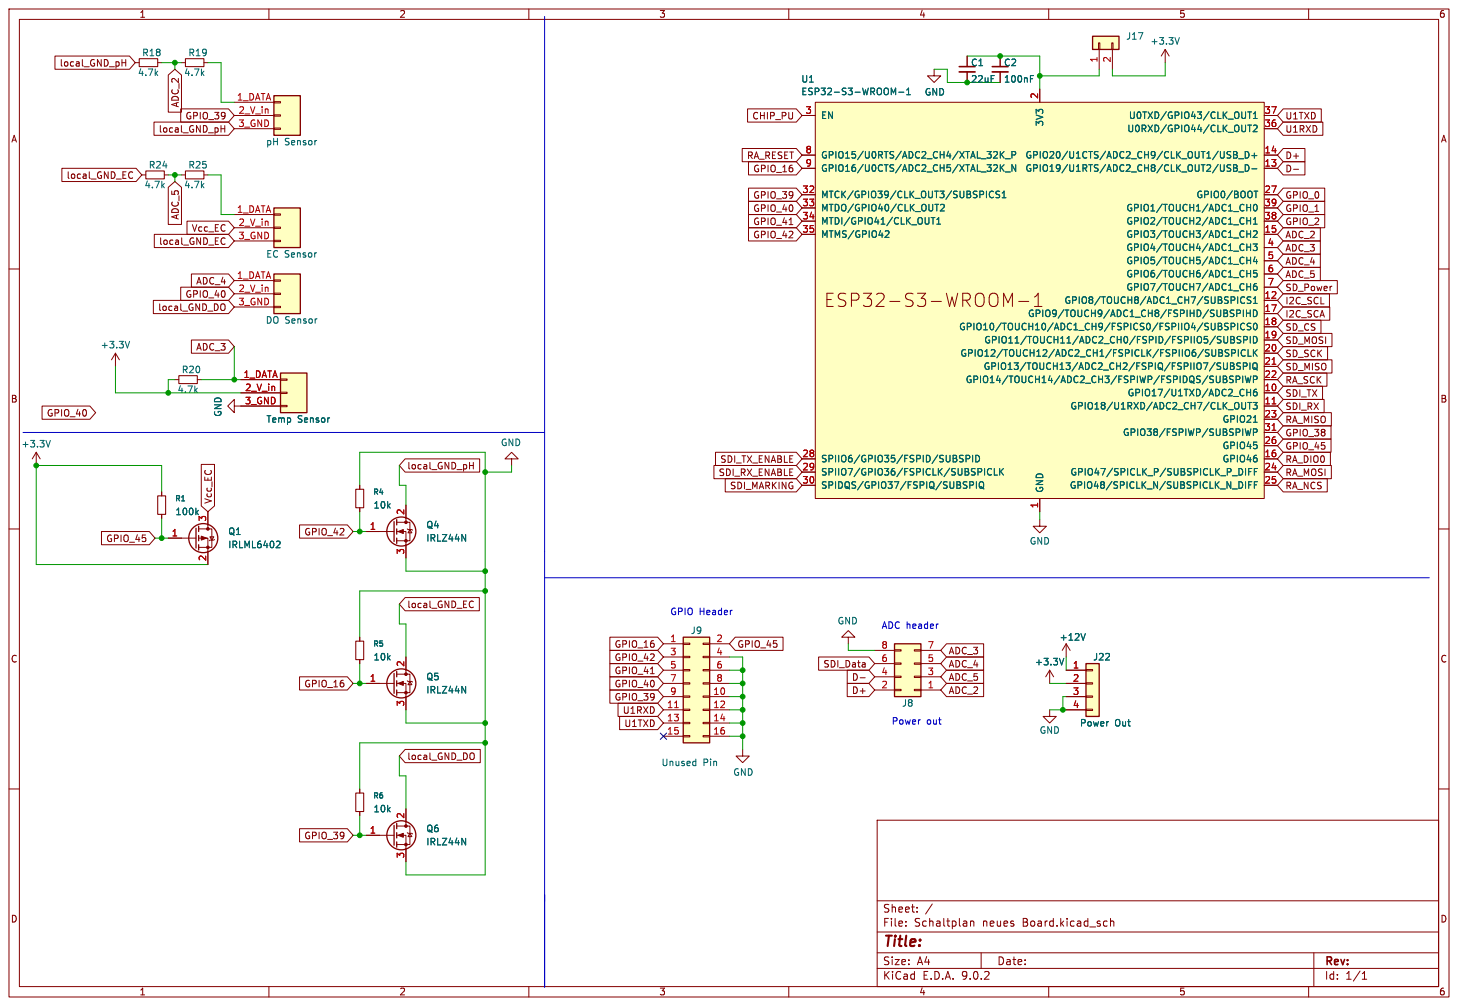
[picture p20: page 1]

1 U0TXD/GPIO43/CLK_OUT1 37 U0RXD/GPIO44/CLK_OUT2 36 GPIO20/U1CTS/ADC2_CH9/CLK_OUT1/USB_D+ 14 GPIO19/U1RTS/ADC2_CH8/CLK_OUT2/USB_D- 13 GPIO0/BOOT 27 GPIO1/TOUCH1/ADC1_CH0 39 GPIO2/TOUCH2/ADC1_CH1 38 GPIO3/TOUCH3/ADC1_CH2 15 GPIO4/TOUCH4/ADC1_CH3 4 GPIO5/TOUCH5/ADC1_CH4 5 GPIO6/TOUCH6/ADC1_CH5 6 GPIO7/TOUCH7/ADC1_CH6 7 GPIO8/TOUCH8/ADC1_CH7/SUBSPICS1 12 GPIO9/TOUCH9/ADC1_CH8/FSPIHD/SUBSPIHD 17 GPIO10/TOUCH10/ADC1_CH9/FSPICS0/FSPIIO4/SUBSPICS0 18 GPIO11/TOUCH11/ADC2_CH0/FSPID/FSPIIO5/SUBSPID 19 GPIO12/TOUCH12/ADC2_CH1/FSPICLK/FSPIIO6/SUBSPICLK 20 GPIO13/TOUCH13/ADC2_CH2/FSPIQ/FSPIIO7/SUBSPIQ 21 GPIO14/TOUCH14/ADC2_CH3/FSPIWP/FSPIDQS/SUBSPIWP 22 GPIO17/U1TXD/ADC2_CH6 10 GPIO18/U1RXD/ADC2_CH7/CLK_OUT3 11 GPIO21 23 GPIO38/FSPIWP/SUBSPIWP 31 GPIO45 26 GPIO46 16 GPIO47/SPICLK_P/SUBSPICLK_P_DIFF 24 GPIO48/SPICLK_N/SUBSPICLK_N_DIFF 25 C1

1 U0TXD/GPIO43/CLK_OUT1 37 U0RXD/GPIO44/CLK_OUT2 36 GPIO20/U1CTS/ADC2_CH9/CLK_OUT1/USB_D+ 14 GPIO19/U1RTS/ADC2_CH8/CLK_OUT2/USB_D- 13 GPIO0/BOOT 27 GPIO1/TOUCH1/ADC1_CH0 39 GPIO2/TOUCH2/ADC1_CH1 38 GPIO3/TOUCH3/ADC1_CH2 15 GPIO4/TOUCH4/ADC1_CH3 4 GPIO5/TOUCH5/ADC1_CH4 5 GPIO6/TOUCH6/ADC1_CH5 6 GPIO7/TOUCH7/ADC1_CH6 7 GPIO8/TOUCH8/ADC1_CH7/SUBSPICS1 12 GPIO9/TOUCH9/ADC1_CH8/FSPIHD/SUBSPIHD 17 GPIO10/TOUCH10/ADC1_CH9/FSPICS0/FSPIIO4/SUBSPICS0 18 GPIO11/TOUCH11/ADC2_CH0/FSPID/FSPIIO5/SUBSPID 19 GPIO12/TOUCH12/ADC2_CH1/FSPICLK/FSPIIO6/SUBSPICLK 20 GPIO13/TOUCH13/ADC2_CH2/FSPIQ/FSPIIO7/SUBSPIQ 21 GPIO14/TOUCH14/ADC2_CH3/FSPIWP/FSPIDQS/SUBSPIWP 22 GPIO17/U1TXD/ADC2_CH6 10 GPIO18/U1RXD/ADC2_CH7/CLK_OUT3 11 GPIO21 23 GPIO38/FSPIWP/SUBSPIWP 31 GPIO45 26 GPIO46 16 GPIO47/SPICLK_P/SUBSPICLK_P_DIFF 24 GPIO48/SPICLK_N/SUBSPICLK_N_DIFF 25 U1ESP32-S3-WROOM-1 GND GND
RA_RESET GPIO_16 GPIO_40 GPIO_41 SDI_MARKING

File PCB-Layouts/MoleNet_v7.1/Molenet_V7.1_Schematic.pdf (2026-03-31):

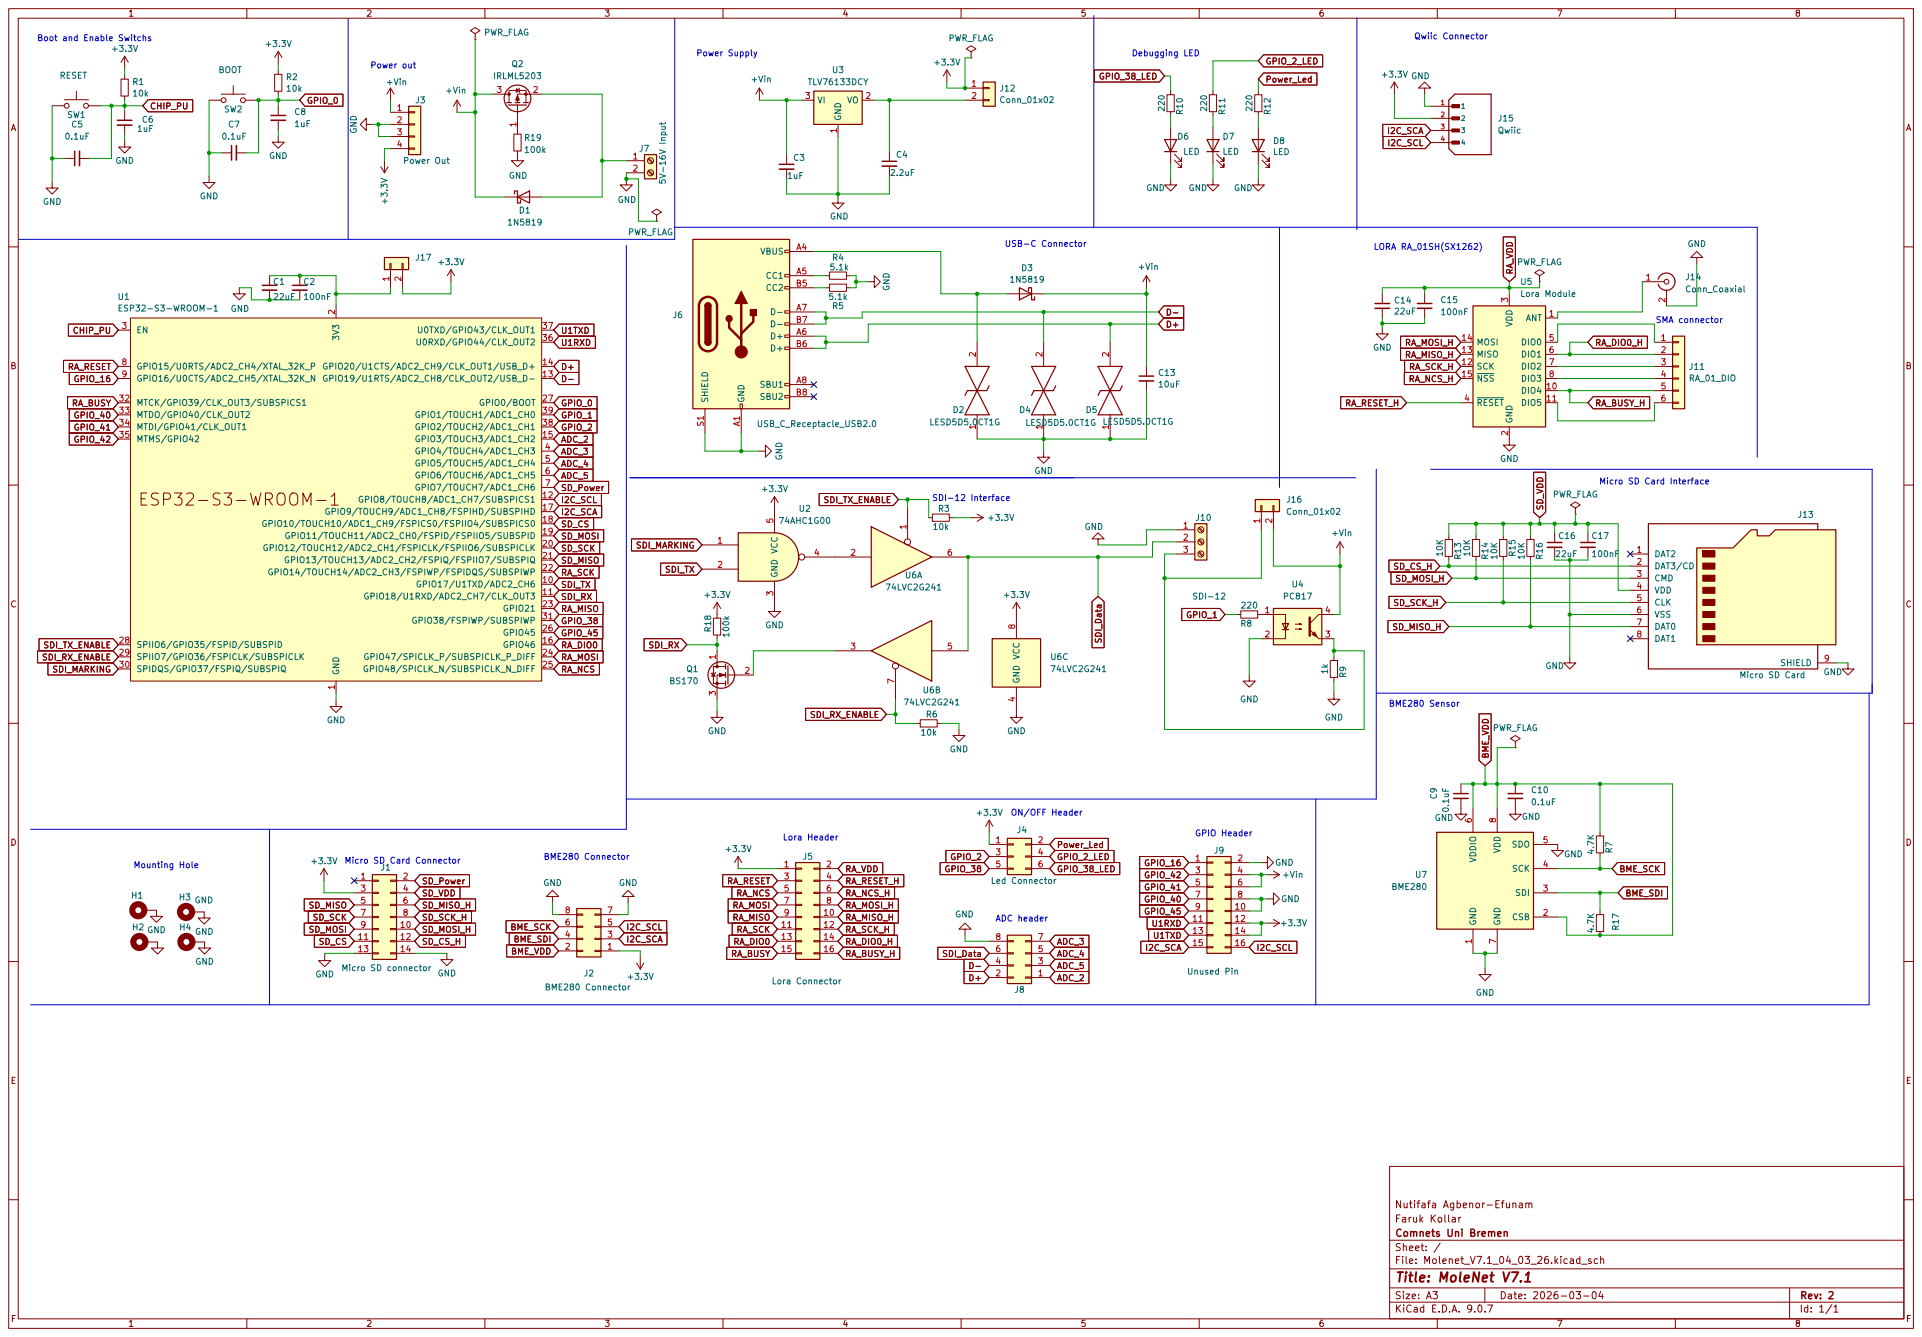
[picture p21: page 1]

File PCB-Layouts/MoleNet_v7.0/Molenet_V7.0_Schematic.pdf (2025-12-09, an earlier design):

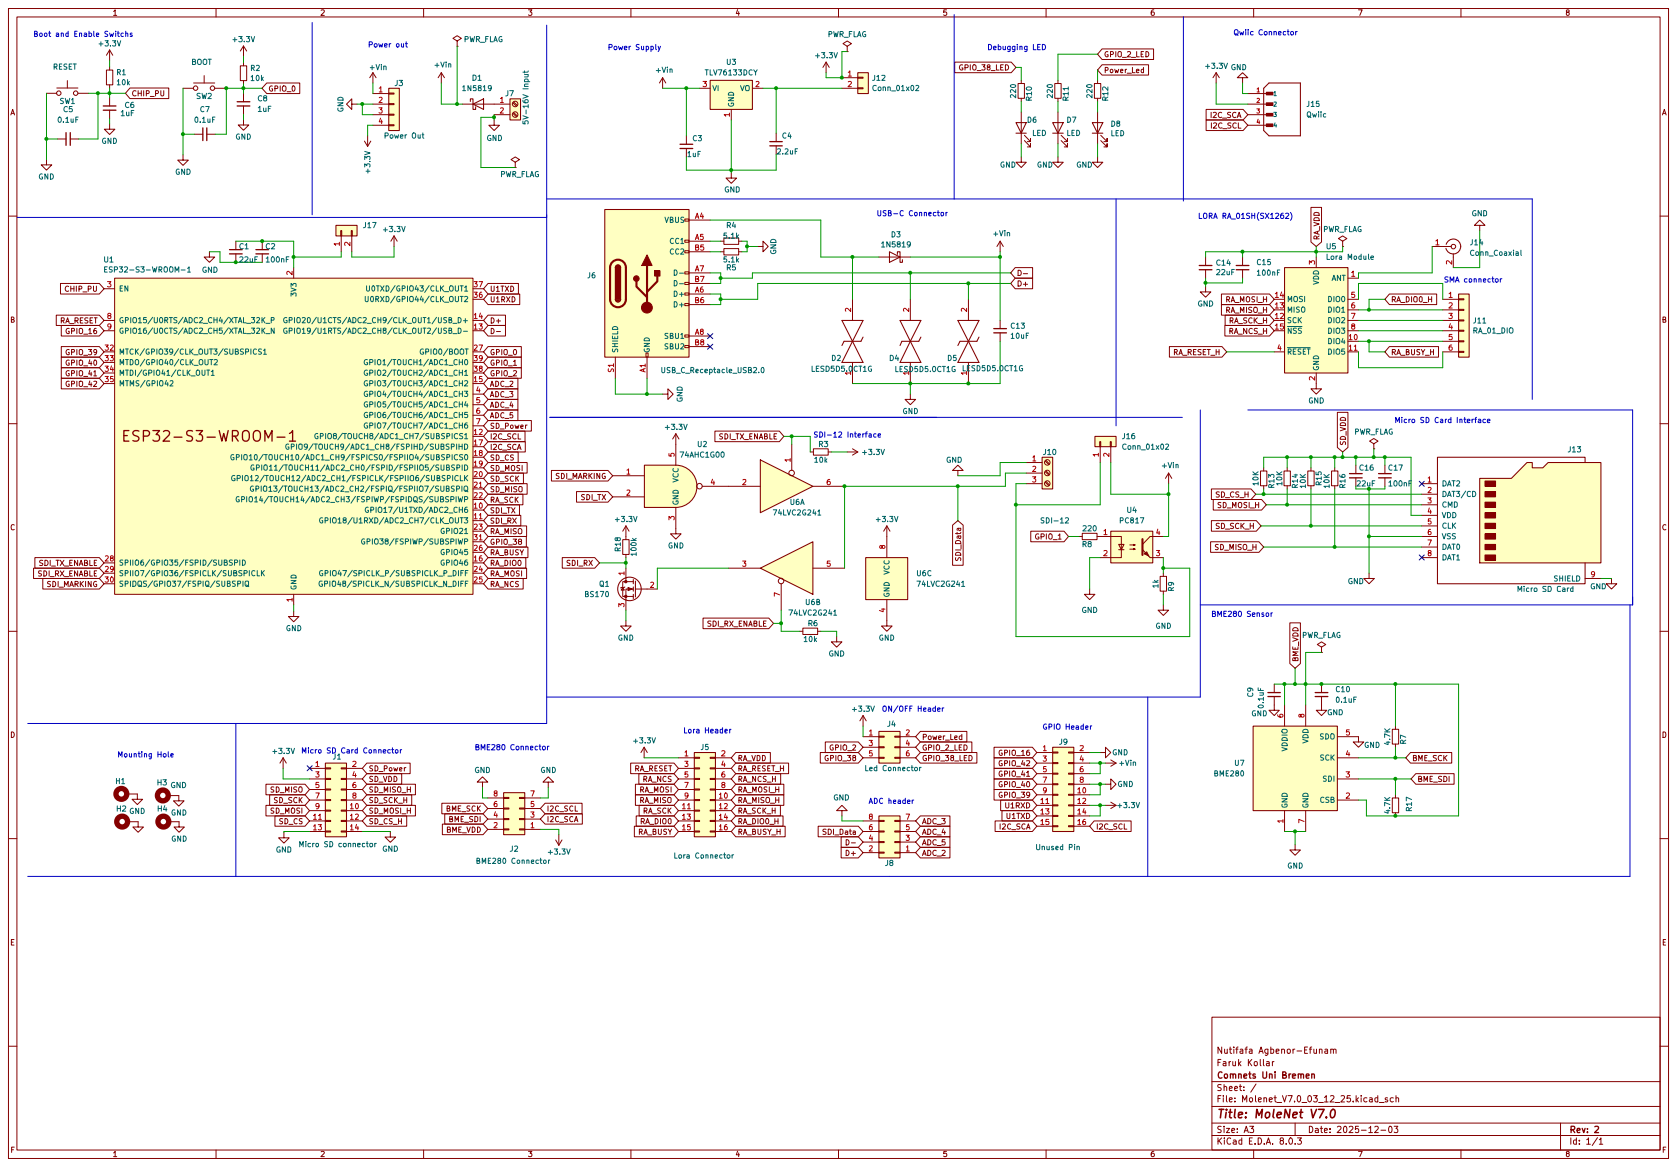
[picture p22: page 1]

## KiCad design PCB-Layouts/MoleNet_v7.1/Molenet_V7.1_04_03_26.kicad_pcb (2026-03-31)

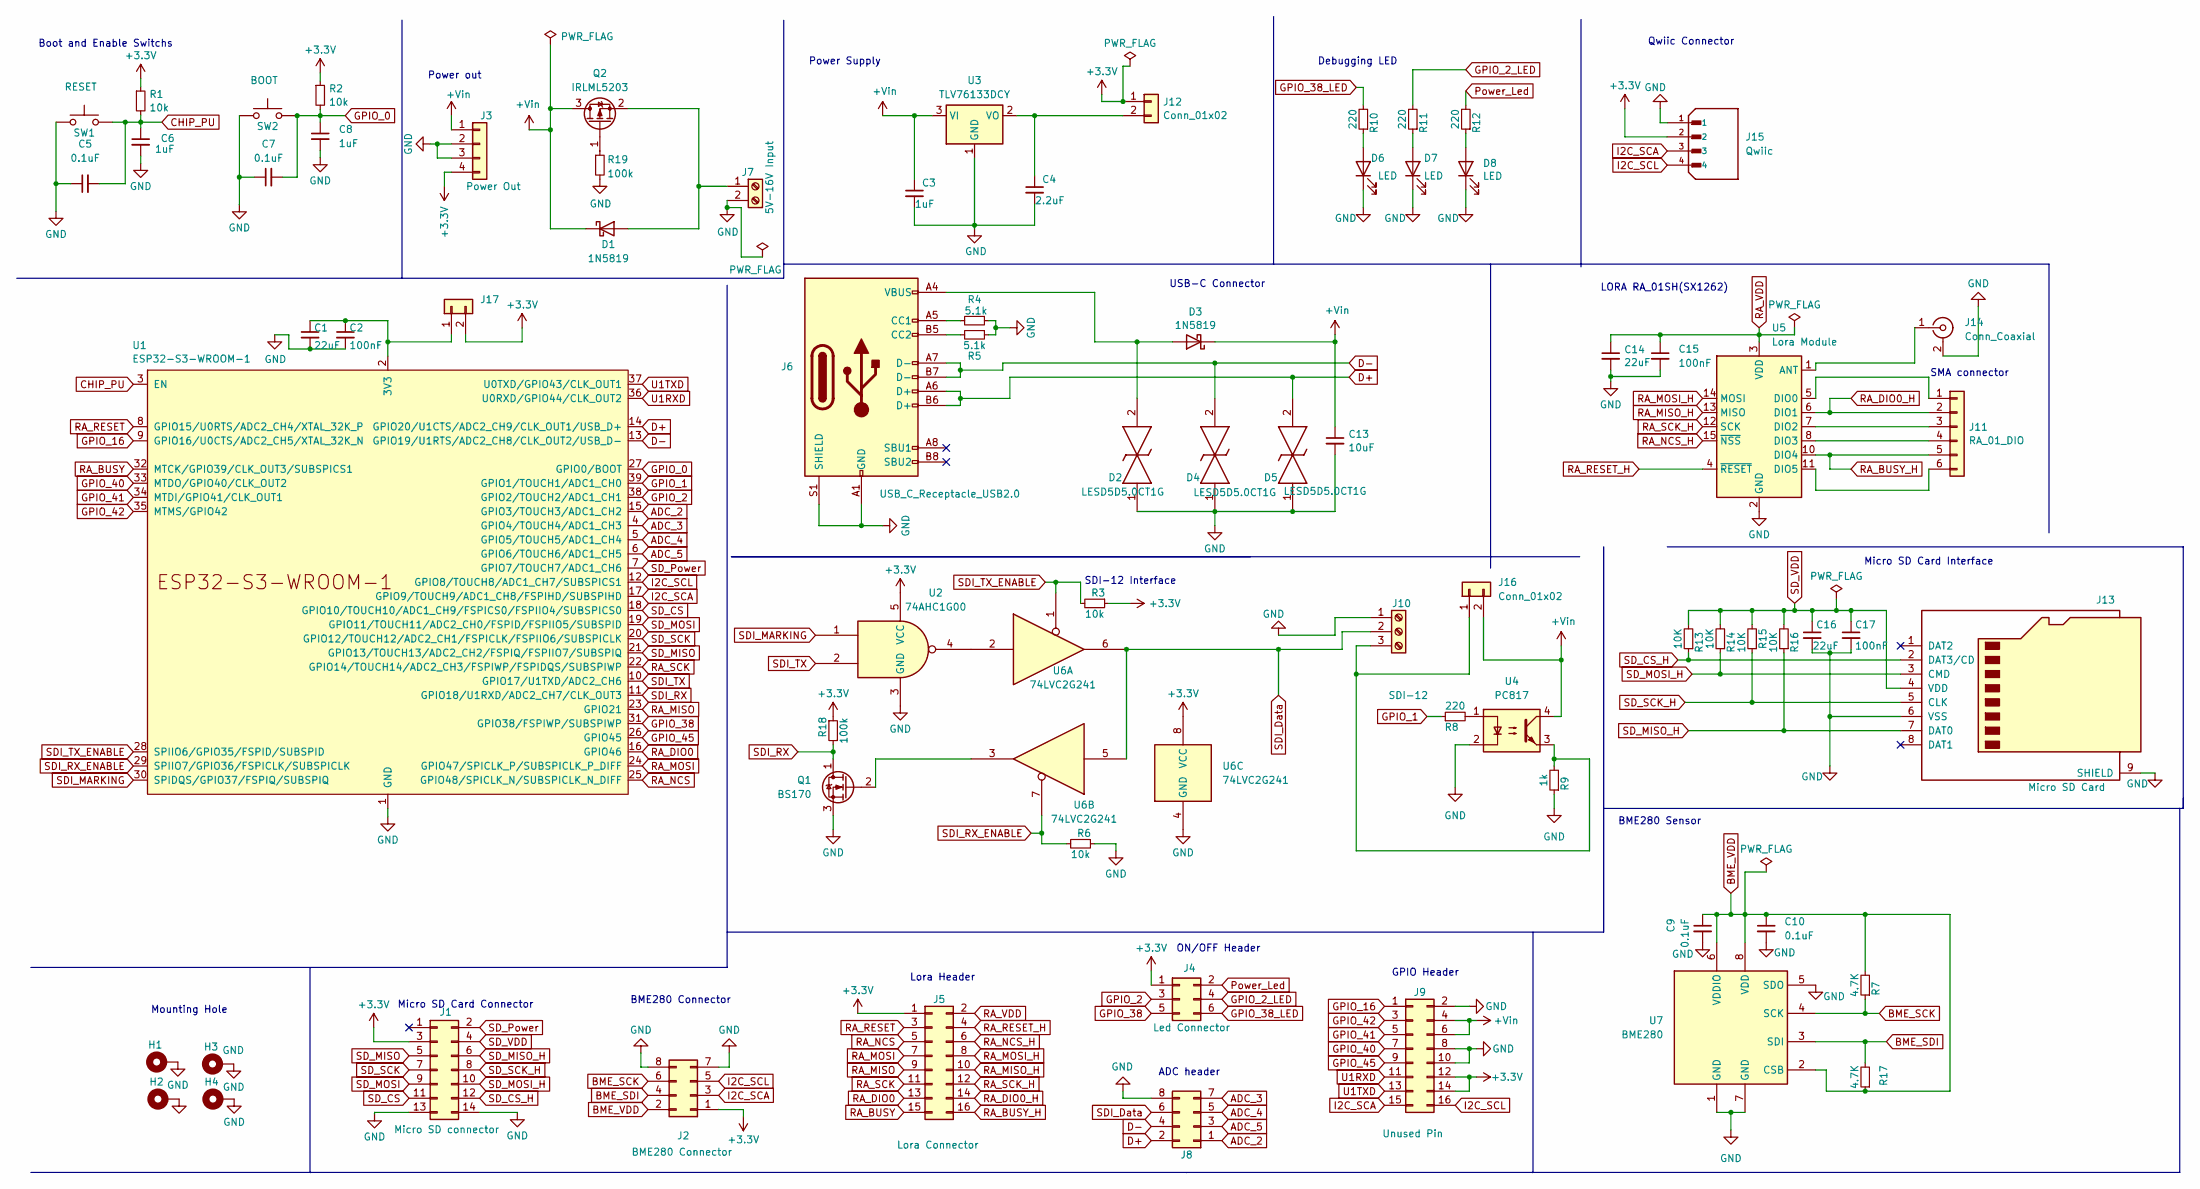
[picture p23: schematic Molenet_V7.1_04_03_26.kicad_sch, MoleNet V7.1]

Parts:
C1, C14: 22uF; C_0805_2012Metric_Pad1.18x1.45mm_HandSolder
C2, C15: 100nF; C_0805_2012Metric_Pad1.18x1.45mm_HandSolder
C3, C6, C8: 1uF; C_0805_2012Metric_Pad1.18x1.45mm_HandSolder
C4: 2.2uF; C_0805_2012Metric_Pad1.18x1.45mm_HandSolder
C5, C7, C9, C10: 0.1uF; C_0805_2012Metric_Pad1.18x1.45mm_HandSolder
C13: 10uF; C_0805_2012Metric_Pad1.18x1.45mm_HandSolder
C16: 22uF; C_0402_1005Metric_Pad0.74x0.62mm_HandSolder
C17: 100nF; C_0402_1005Metric_Pad0.74x0.62mm_HandSolder
D1, D3: 1N5819; D_DO-41_SOD81_P10.16mm_Horizontal
D2, D4, D5: LESD5D5.0CT1G; LESD5D50CT1G; Manufacturer_Part_Number LESD5D5.0CT1G; JLC PART C383211
D6, D7, D8: LED; LED_0805_2012Metric_Pad1.15x1.40mm_HandSolder
H1, H2, H3, H4: MountingHole_Pad; MountingHole_3.2mm_M3_Pad
J1: Micro SD connector; PinHeader_2x07_P2.54mm_Vertical
J2: BME280 Connector; PinHeader_2x04_P2.54mm_Vertical
J3: Power Out; PinHeader_1x04_P2.54mm_Vertical
J4: Led Connector; PinHeader_2x03_P2.54mm_Vertical
J5: Lora Connector; PinHeader_2x08_P2.54mm_Vertical
J6: USB_C_Receptacle_USB2.0; USB_C_Receptacle_G-Switch_GT-USB-7010ASV; JLC PART C2936185
J7: 5V-16V Input; TerminalBlock_Phoenix_PT-1,5-2-3.5-H_1x02_P3.50mm_Horizontal; JLC PART C89122
J8: PinHeader_2x04_P2.54mm_Vertical
J9: Unused Pin; PinHeader_2x08_P2.54mm_Vertical
J10: SDI-12; TerminalBlock_Phoenix_PT-1,5-3-3.5-H_1x03_P3.50mm_Horizontal; JLC PART C91152
J11: RA_01_DIO; PinHeader_1x06_P2.54mm_Vertical
J12, J16, J17: Conn_01x02; PinHeader_1x02_P2.54mm_Vertical
J13: Micro SD Card; microSD_HC_Molex_104031-0811; JLC PART C428492
J14: Conn_Coaxial; SMA_Amphenol_901-143_Horizontal; JLC PART C914554
J15: Qwiic; SPARKFUN_PRT-14417; PARTREV NA
Q1: BS170; TO-92_Inline
Q2: IRLML5203; SOT-23
R1, R2, R3, R6: 10k; R_0805_2012Metric_Pad1.20x1.40mm_HandSolder
R4, R5: 5.1k; R_0402_1005Metric_Pad0.72x0.64mm_HandSolder
R7, R17: 4.7K; R_0402_1005Metric_Pad0.72x0.64mm_HandSolder
R8, R10, R11, R12: 220; R_0805_2012Metric_Pad1.20x1.40mm_HandSolder
R9: 1k; R_0805_2012Metric_Pad1.20x1.40mm_HandSolder
R13, R14, R15, R16: 10K; R_0402_1005Metric_Pad0.72x0.64mm_HandSolder
R18, R19: 100k; R_0805_2012Metric_Pad1.20x1.40mm_HandSolder
SW1: RESET; SW_PUSH_6mm_H4.3mm; JLC PART C273464
SW2: BOOT; SW_PUSH_6mm_H4.3mm; JLC PART C273464
U1: ESP32-S3-WROOM-1; JLC PART C2913198
U2: 74AHC1G00; SC-74A-5_1.55x2.9mm_P0.95mm
U3: TLV76133DCY; SOT-223-3_TabPin2
U4: PC817; DIP-4_W7.62mm
U5: Lora Module; Ai-Thinker-Ra-01-LoRa
U6: 74LVC2G241; SOP65P400X130-8N
U7: BME280; Bosch_LGA-8_2.5x2.5mm_P0.65mm_ClockwisePinNumbering

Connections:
+3.3V: J1.3, J2.1, J3.4, J4.1, J5.1, J9.12, J9.14, J12.1, J15.2, J17.2, R1.1, R2.1, R3.1, R18.1, U2.5 (VCC), U6.8 (VCC)
+Vin: C3.1, C13.1, D1.1 (K), D3.1 (K), J3.1, J9.4, J9.6, J16.2, Q2.3 (D), U3.3 (VI), U4.4
ADC_2: J8.1, U1.15 (GPIO3/TOUCH3/ADC1_CH2)
ADC_3: J8.7 (Pin_4), U1.4 (GPIO4/TOUCH4/ADC1_CH3)
ADC_4: J8.5 (Pin_3), U1.5 (GPIO5/TOUCH5/ADC1_CH4)
ADC_5: J8.3 (Pin_2), U1.6 (GPIO6/TOUCH6/ADC1_CH5)
BME_SCK: J2.6 (Pin_7), R7.1, U7.4 (SCK)
BME_SDI: J2.4 (Pin_6), R17.2, U7.3 (SDI)
BME_VDD: C9.1, C10.1, J2.2 (Pin_5), R7.2, R17.1, U7.2 (CSB), U7.6 (VDDIO), U7.8 (VDD)
CHIP_PU: C5.2, C6.1, R1.2, SW1.2, U1.3 (EN)
D+: D5.2, J6.A6 (D+), J6.B6 (D+), J8.2 (Pin_5), U1.14 (GPIO20/U1CTS/ADC2_CH9/CLK_OUT1/USB_D+)
D-: D4.2, J6.A7 (D-), J6.B7 (D-), J8.4 (Pin_6), U1.13 (GPIO19/U1RTS/ADC2_CH8/CLK_OUT2/USB_D-)
GND: C1.2, C2.2, C3.2, C4.2, C5.1, C6.2, C7.1, C8.2, C9.2, C10.2, C13.2, C14.2, C15.2, C16.2, C17.2, D2.1, D4.1, D5.1, D6.1 (K), D7.1 (K), D8.1 (K), H1.1, H2.1, H3.1, H4.1, J1.13, J1.14, J2.7 (Pin_4), J2.8, J3.2, J3.3, J6.A1 (GND), J6.A12 (GND), J6.B1 (GND), J6.B12 (GND), J6.S1 (SHIELD), J7.2, J8.8, J9.2, J9.8, J9.10, J10.1, J13.6 (VSS), J13.9 (SHIELD), J14.2 (Ext), J15.1, Q1.3 (S), R4.1, R5.1, R6.1, R9.1, R19.2, SW1.1, SW2.1, U1.1 (GND), U1.40 (GND), U1.41 (GND), U2.3 (GND), U3.1 (GND), U4.2, U5.2 (GND), U5.9 (GND), U5.16 (GND), U6.4 (GND), U7.1 (GND), U7.5 (SDO), U7.7 (GND)
GPIO_0: C7.2, C8.1, R2.2, SW2.2, U1.27 (GPIO0/BOOT)
GPIO_1: R8.1, U1.39 (GPIO1/TOUCH1/ADC1_CH0)
GPIO_2: J4.3 (Pin_2), U1.38 (GPIO2/TOUCH2/ADC1_CH1)
GPIO_2_LED: J4.4 (Pin_5), R11.2
GPIO_16: J9.1, U1.9 (GPIO16/U0CTS/ADC2_CH5/XTAL_32K_N)
GPIO_38: J4.5 (Pin_3), U1.31 (GPIO38/FSPIWP/SUBSPIWP)
GPIO_38_LED: J4.6, R10.2
GPIO_40: J9.7, U1.33 (MTDO/GPIO40/CLK_OUT2)
GPIO_41: J9.5, U1.34 (MTDI/GPIO41/CLK_OUT1)
GPIO_42: J9.3, U1.35 (MTMS/GPIO42)
GPIO_45: J9.9, U1.26 (GPIO45)
I2C_SCA: J2.3 (Pin_2), J9.15, J15.3, U1.17 (GPIO9/TOUCH9/ADC1_CH8/FSPIHD/SUBSPIHD)
I2C_SCL: J2.5 (Pin_3), J9.16, J15.4, U1.12 (GPIO8/TOUCH8/ADC1_CH7/SUBSPICS1)
unnamed: D1.2 (A), J7.1, Q2.2 (S)
unnamed: D2.2, D3.2 (A), J6.A4 (VBUS), J6.A9 (VBUS), J6.B4 (VBUS), J6.B9 (VBUS)
unnamed: D6.2 (A), R10.1
unnamed: D7.2 (A), R11.1
unnamed: D8.2 (A), R12.1
unnamed: J6.A5 (CC1), R4.2
unnamed: J6.B5 (CC2), R5.2
unnamed: J10.3, J16.1, R9.2, U4.3
unnamed: J11.1, U5.5 (DIO0)
unnamed: J11.3, U5.7 (DIO2)
unnamed: J11.4, U5.8 (DIO3)
unnamed: J11.6, U5.11 (DIO5)
unnamed: C4.1, J12.2, U3.2 (VO)
unnamed: J14.1 (In), U5.1 (ANT)
unnamed: C1.1, C2.1, J17.1, U1.2 (3V3)
unnamed: Q1.2 (G), U6.3
unnamed: Q2.1 (G), R19.1
unnamed: R8.2, U4.1
unnamed: U2.4, U6.2
Power_Led: J4.2 (Pin_4), R12.2
RA_BUSY: J5.15, U1.32 (MTCK/GPIO39/CLK_OUT3/SUBSPICS1)
RA_BUSY_H: J5.16, J11.5, U5.10 (DIO4)
RA_DIO0: J5.13, U1.16 (GPIO46)
RA_DIO0_H: J5.14, J11.2, U5.6 (DIO1)
RA_MISO: J5.9, U1.23 (GPIO21)
RA_MISO_H: J5.10, U5.13 (MISO)
RA_MOSI: J5.7, U1.24 (GPIO47/SPICLK_P/SUBSPICLK_P_DIFF)
RA_MOSI_H: J5.8, U5.14 (MOSI)
RA_NCS: J5.5, U1.25 (GPIO48/SPICLK_N/SUBSPICLK_N_DIFF)
RA_NCS_H: J5.6, U5.15 (~NSS)
RA_RESET: J5.3, U1.8 (GPIO15/U0RTS/ADC2_CH4/XTAL_32K_P)
RA_RESET_H: J5.4, U5.4 (~RESET)
RA_SCK: J5.11, U1.22 (GPIO14/TOUCH14/ADC2_CH3/FSPIWP/FSPIDQS/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)
RA_SCK_H: J5.12, U5.12 (SCK)
RA_VDD: C14.1, C15.1, J5.2, U5.3 (VDD)
SDI_Data: J8.6 (Pin_7), J10.2, U6.5, U6.6
SDI_MARKING: U1.30 (SPIDQS/GPIO37/FSPIQ/SUBSPIQ), U2.1
SDI_RX: Q1.1 (D), R18.2, U1.11 (GPIO18/U1RXD/ADC2_CH7/CLK_OUT3)
SDI_RX_ENABLE: R6.2, U1.29 (SPIIO7/GPIO36/FSPICLK/SUBSPICLK), U6.7
SDI_TX: U1.10 (GPIO17/U1TXD/ADC2_CH6), U2.2
SDI_TX_ENABLE: R3.2, U1.28 (SPIIO6/GPIO35/FSPID/SUBSPID), U6.1
SD_CS: J1.11, U1.18 (GPIO10/TOUCH10/ADC1_CH9/FSPICS0/FSPIIO4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)
SD_CS_H: J1.12, J13.2 (DAT3/CD), R13.1
SD_MISO: J1.5, U1.21 (GPIO13/TOUCH13/ADC2_CH2/FSPIQ/FSPIIO7/S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)
SD_MISO_H: J1.6, J13.7 (DAT0), R16.1
SD_MOSI: J1.9, U1.19 (GPIO11/TOUCH11/ADC2_CH0/FSPID/FSPIIO5/S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)
SD_MOSI_H: J1.10, J13.3 (CMD), R14.1
SD_Power: J1.2, U1.7 (GPIO7/TOUCH7/ADC1_CH6)
SD_SCK: J1.7, U1.20 (GPIO12/TOUCH12/ADC2_CH1/FSPICLK/FSPIIO6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)
SD_SCK_H: J1.8, J13.5 (CLK), R15.1
SD_VDD: C16.1, C17.1, J1.4, J13.4 (VDD), R13.2, R14.2, R15.2, R16.2
U1RXD: J9.11, U1.36 (U0RXD/GPIO44/CLK_OUT2)
U1TXD: J9.13, U1.37 (U0TXD/GPIO43/CLK_OUT1)

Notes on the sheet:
Lora Header
ON/OFF Header
Boot and Enable Switchs
SMA connector
Debugging LED
LORA RA_01SH(SX1262)
Power Supply
USB-C Connector
Power out
GPIO Header
Micro SD Card Connector
SDI-12 Interface
ADC header
BME280 Sensor
Qwiic Connector
Mounting Hole
BME280 Connector
Micro SD Card Interface

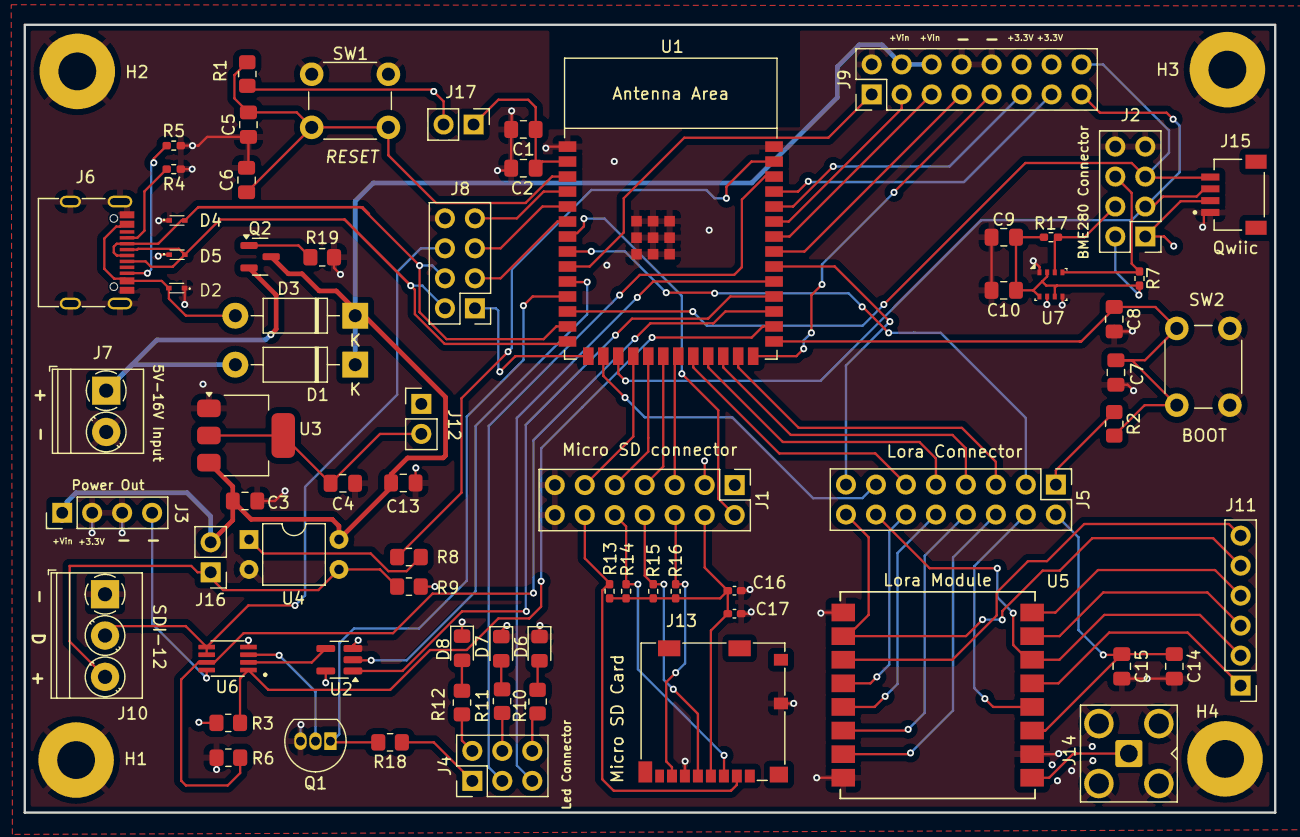
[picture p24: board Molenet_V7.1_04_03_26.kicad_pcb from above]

Board: 4 copper layers, 106.0 x 66.8 mm, 75 parts (1 on the bottom side), 79 nets.

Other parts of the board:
G2: LOGO

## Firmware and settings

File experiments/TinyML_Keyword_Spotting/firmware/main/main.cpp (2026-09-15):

#include <stdio.h>
#include <stdint.h>
#include <stdlib.h>
#include <math.h>
#include <limits.h>

#include <vector>

#include "esp_log.h"
#include "esp_timer.h"
#include "esp_err.h"

#include "freertos/FreeRTOS.h"
#include "freertos/task.h"

#include "driver/gpio.h"
#include "driver/i2s_std.h"

#include "kiss_fft.h"
#include "kiss_fftr.h"

#include "dl_model_base.hpp"
#include "dl_tensor_base.hpp"


// ============================================================
// TAG
// ============================================================

static const char *TAG = "KWS_LIVE";


// ============================================================
// AUDIO CONFIGURATION
// ============================================================

static constexpr int SAMPLE_RATE = 16000;

// Model/MFCC receives exactly one second.
static constexpr int AUDIO_SAMPLES = 16000;

// Record two seconds so the user does not need to hit
// an exact one-second timing window.
static constexpr int CAPTURE_SECONDS = 2;

static constexpr int CAPTURE_SAMPLES =
    SAMPLE_RATE * CAPTURE_SECONDS;


// Speech-window search:
// 100 ms energy window
// 25 ms hop

static constexpr int ENERGY_WINDOW_SAMPLES =
    SAMPLE_RATE / 10;

static constexpr int ENERGY_HOP_SAMPLES =
    SAMPLE_RATE / 40;


// ============================================================
// MFCC CONFIGURATION
// ============================================================

static constexpr int N_FFT = 1024;

static constexpr int WIN_LENGTH = 800;

static constexpr int HOP_LENGTH = 160;

static constexpr int N_MELS = 128;

static constexpr int N_MFCC = 40;

static constexpr int N_FRAMES = 101;

static constexpr int N_FREQ =
    N_FFT / 2 + 1;

static constexpr int WINDOW_OFFSET =
    (N_FFT - WIN_LENGTH) / 2;


// ============================================================
// AUDIO QUALITY SETTINGS
// ============================================================

// Quiet-room RMS was around 0.010.
//
// Reject recordings below 0.030.

static constexpr float SILENCE_RMS_THRESHOLD =
    0.030f;


// Treat values close to full scale as clipping.

static constexpr float CLIP_LEVEL =
    0.98f;


// Reject if more than 1% of selected samples are clipped.

static constexpr float MAX_CLIPPED_FRACTION =
    0.01f;


// Do hardware action only when prediction >= 70%.

static constexpr float MIN_CONFIDENCE =
    0.70f;


// ============================================================
// LAST AUDIO STATISTICS
// ============================================================

static float last_audio_rms =
    0.0f;

static float last_audio_peak =
    0.0f;

static float last_clipped_fraction =
    0.0f;

static float last_selected_start_seconds =
    0.0f;


// ============================================================
// MOLeNET V7.1 + INMP441
// ============================================================
//
// SCK = GPIO40
// WS  = GPIO41
// SD  = GPIO42
//
// L/R = GND
//
// LEFT I2S channel
//
// ============================================================

static constexpr gpio_num_t MIC_BCLK =
    GPIO_NUM_40;

static constexpr gpio_num_t MIC_WS =
    GPIO_NUM_41;

static constexpr gpio_num_t MIC_SD =
    GPIO_NUM_42;


// ============================================================
// I2S HANDLE
// ============================================================

static i2s_chan_handle_t mic_rx_handle =
    nullptr;


// ============================================================
// EMBEDDED ESP-DL MODEL
// ============================================================

extern const uint8_t kws_model[]
    asm("_binary_kws_3class_espdl_start");


// ============================================================
// EMBEDDED MFCC PARAMETERS
// ============================================================

extern const uint8_t hann_window_bin[]
    asm("_binary_hann_window_bin_start");

extern const uint8_t mel_filterbank_transposed_bin[]
    asm("_binary_mel_filterbank_transposed_bin_start");

extern const uint8_t dct_matrix_bin[]
    asm("_binary_dct_matrix_bin_start");


// ============================================================
// CLASS LABELS
// ============================================================

static const char *CLASS_NAMES[3] =
{
    "YES",
    "NO",
    "UP"
};


// ============================================================
// MOLeNET V7.1 ONBOARD ACTION LED
// ============================================================
//
// D6 = GPIO38
//
// GPIO HIGH -> LED ON
// GPIO LOW  -> LED OFF
//
// Actions:
//
// YES -> ON
// NO  -> OFF
// UP  -> blink 3 times
//
// ============================================================

static constexpr gpio_num_t ACTION_LED =
    GPIO_NUM_38;


static bool action_led_state =
    false;


// ============================================================
// INITIALIZE ACTION LED
// ============================================================

static void init_action_led()
{
    gpio_config_t cfg = {};

    cfg.pin_bit_mask =
        (1ULL << ACTION_LED);

    cfg.mode =
        GPIO_MODE_OUTPUT;

    cfg.pull_up_en =
        GPIO_PULLUP_DISABLE;

    cfg.pull_down_en =
        GPIO_PULLDOWN_DISABLE;

    cfg.intr_type =
        GPIO_INTR_DISABLE;


    ESP_ERROR_CHECK(
        gpio_config(
            &cfg
        )
    );


    // Start OFF.

    gpio_set_level(
        ACTION_LED,
        0
    );


    action_led_state =
        false;


    ESP_LOGI(
        TAG,
        "Onboard action LED initialized on GPIO38 / D6"
    );
}


// ============================================================
// LED ON
// ============================================================

static void action_led_on()
{
    gpio_set_level(
        ACTION_LED,
        1
    );


    action_led_state =
        true;


    ESP_LOGI(
        TAG,
        "ACTION: YES -> D6 LED ON"
    );
}


// ============================================================
// LED OFF
// ============================================================

static void action_led_off()
{
    gpio_set_level(
        ACTION_LED,
        0
    );


    action_led_state =
        false;


    ESP_LOGI(
        TAG,
        "ACTION: NO -> D6 LED OFF"
    );
}


// ============================================================
// LED BLINK
// ============================================================

static void action_led_blink_three_times()
{
    // Remember previous state.

    const bool previous_state =
        action_led_state;


    ESP_LOGI(
        TAG,
        "ACTION: UP -> D6 LED BLINK 3 TIMES"
    );


    for (
        int i = 0;
        i < 3;
        i++
    )
    {
        gpio_set_level(
            ACTION_LED,
            1
        );


        vTaskDelay(
            pdMS_TO_TICKS(
                250
            )
        );


        gpio_set_level(
            ACTION_LED,
            0
        );


        vTaskDelay(
            pdMS_TO_TICKS(
                250
            )
        );
    }


    // Restore state from before blinking.

    gpio_set_level(
        ACTION_LED,
        previous_state ? 1 : 0
    );


    action_led_state =
        previous_state;
}


// ============================================================
// INITIALIZE INMP441
// ============================================================

static void init_microphone()
{
    ESP_LOGI(
        TAG,
        "Initializing INMP441..."
    );


    // ========================================================
    // I2S RX CHANNEL
    // ========================================================

    i2s_chan_config_t chan_cfg =
        I2S_CHANNEL_DEFAULT_CONFIG(
            I2S_NUM_1,
            I2S_ROLE_MASTER
        );


    ESP_ERROR_CHECK(
        i2s_new_channel(
            &chan_cfg,
            nullptr,
            &mic_rx_handle
        )
    );


    // ========================================================
    // I2S STANDARD CONFIG
    // ========================================================

    i2s_std_config_t rx_cfg = {};


    rx_cfg.clk_cfg =
        I2S_STD_CLK_DEFAULT_CONFIG(
            SAMPLE_RATE
        );


    rx_cfg.clk_cfg.mclk_multiple =
        I2S_MCLK_MULTIPLE_256;


    rx_cfg.slot_cfg =
        I2S_STD_PHILIPS_SLOT_DEFAULT_CONFIG(
            I2S_DATA_BIT_WIDTH_32BIT,
            I2S_SLOT_MODE_MONO
        );


    // ========================================================
    // MATCH WORKING MOLeNET / XIAOZHI CONFIG
    // ========================================================

    rx_cfg.slot_cfg.slot_mask =
        I2S_STD_SLOT_LEFT;


    rx_cfg.slot_cfg.ws_width =
        I2S_DATA_BIT_WIDTH_32BIT;


    rx_cfg.slot_cfg.ws_pol =
        false;


    rx_cfg.slot_cfg.bit_shift =
        true;


#ifdef I2S_HW_VERSION_2

    rx_cfg.slot_cfg.left_align =
        true;


    rx_cfg.slot_cfg.big_endian =
        false;


    rx_cfg.slot_cfg.bit_order_lsb =
        false;

#endif


    // ========================================================
    // GPIO
    // ========================================================

    rx_cfg.gpio_cfg.mclk =
        I2S_GPIO_UNUSED;


    rx_cfg.gpio_cfg.bclk =
        MIC_BCLK;


    rx_cfg.gpio_cfg.ws =
        MIC_WS;


    rx_cfg.gpio_cfg.dout =
        I2S_GPIO_UNUSED;


    rx_cfg.gpio_cfg.din =
        MIC_SD;


    rx_cfg.gpio_cfg.invert_flags.mclk_inv =
        false;


    rx_cfg.gpio_cfg.invert_flags.bclk_inv =
        false;


    rx_cfg.gpio_cfg.invert_flags.ws_inv =
        false;


    // ========================================================
    // INITIALIZE
    // ========================================================

    ESP_ERROR_CHECK(
        i2s_channel_init_std_mode(
            mic_rx_handle,
            &rx_cfg
        )
    );


    ESP_ERROR_CHECK(
        i2s_channel_enable(
            mic_rx_handle
        )
    );


    ESP_LOGI(
        TAG,
        "INMP441 initialized successfully."
    );


    ESP_LOGI(
        TAG,
        "Sample rate : %d Hz",
        SAMPLE_RATE
    );


    ESP_LOGI(
        TAG,
        "SCK/BCLK    : GPIO%d",
        MIC_BCLK
    );


    ESP_LOGI(
        TAG,
        "WS          : GPIO%d",
        MIC_WS
    );


    ESP_LOGI(
        TAG,
        "SD          : GPIO%d",
        MIC_SD
    );


    ESP_LOGI(
        TAG,
        "Channel     : LEFT"
    );
}


// ============================================================
// RECORD TWO SECONDS
// ============================================================
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
extern "C" void app_main(void)
{
    // ========================================================
    // STARTUP INFORMATION
    // ========================================================

    ESP_LOGI(
        TAG,
        "========================================"
    );


    ESP_LOGI(
        TAG,
        "LIVE KEYWORD SPOTTING"
    );


    ESP_LOGI(
        TAG,
        "MoleNet V7.1 + INMP441"
    );


    ESP_LOGI(
        TAG,
        "YES / NO / UP"
    );


    ESP_LOGI(
        TAG,
        "========================================"
    );


    ESP_LOGI(
        TAG,
        "Capture     : %d seconds",
        CAPTURE_SECONDS
    );


    ESP_LOGI(
        TAG,
        "Model audio : 16 kHz / 1 second"
    );


    ESP_LOGI(
        TAG,
        "MFCC        : 40 x 101"
    );


    ESP_LOGI(
        TAG,
        "Silence RMS : %.6f",
        SILENCE_RMS_THRESHOLD
    );


    ESP_LOGI(
        TAG,
        "Confidence  : %.0f %%",
        MIN_CONFIDENCE *
            100.0f
    );


    // ========================================================
    // MICROPHONE
    // ========================================================

    init_microphone();


    // ========================================================
    // ACTION LED
    // ========================================================

    init_action_led();


    // ========================================================
    // STARTUP LED TEST
    // ========================================================
    //
    // D6 / GPIO38 should blink 5 times.
    //
    // THIS TELLS YOU EXACTLY WHICH PHYSICAL LED IS CONTROLLED.
    //
    // After the test it is left OFF.
    //
    // ========================================================

    ESP_LOGI(
        TAG,
        "========================================"
    );


    ESP_LOGI(
        TAG,
        "Testing D6 / GPIO38 LED..."
    );


    for (
        int i = 0;
        i < 5;
        i++
    )
    {
        gpio_set_level(
            ACTION_LED,
            1
        );


        vTaskDelay(
            pdMS_TO_TICKS(
                500
            )
        );


        gpio_set_level(
            ACTION_LED,
            0
        );


        vTaskDelay(
            pdMS_TO_TICKS(
                500
            )
        );
    }


    action_led_state =
        false;


    gpio_set_level(
        ACTION_LED,
        0
    );


    ESP_LOGI(
        TAG,
        "D6 / GPIO38 LED test complete."
    );


    ESP_LOGI(
        TAG,
        "D6 should now be OFF."
    );


    ESP_LOGI(
        TAG,
        "========================================"
    );


    // ========================================================
    // LOAD MODEL
    // ========================================================

    ESP_LOGI(
        TAG,
        "Loading ESP-DL model..."
    );


    dl::Model *model =
        new dl::Model(
            (const char *)kws_model,
            fbs::MODEL_LOCATION_IN_FLASH_RODATA
        );


    if (
        model == nullptr
    )
    {
        ESP_LOGE(
            TAG,
            "Model loading failed."
        );


        return;
    }


    ESP_LOGI(
        TAG,
        "Model loaded successfully."
    );


    dl::TensorBase *model_input =
        model->get_input();


    dl::TensorBase *model_output =
        model->get_output();


    if (
        model_input != nullptr
        &&
        model_output != nullptr
    )
    {
        ESP_LOGI(
            TAG,
            "Model input size  : %d",
            model_input->get_size()
        );


        ESP_LOGI(
            TAG,
            "Model output size : %d",
            model_output->get_size()
        );
    }


    // ========================================================
    // BUFFERS
    // ========================================================

    std::vector<int16_t> capture(
        CAPTURE_SAMPLES
    );


    std::vector<float> audio(
        AUDIO_SAMPLES
    );


    std::vector<float> mfcc(
        N_MFCC *
        N_FRAMES
    );


    // ========================================================
    // LIVE LOOP
    // ========================================================

    while (
        true
    )
    {
        printf("\n\n");


        ESP_LOGI(
            TAG,
            "========================================"
        );


        ESP_LOGI(
            TAG,
            "GET READY"
        );


        ESP_LOGI(
            TAG,
            "Prepare to say ONE word: YES, NO or UP"
        );


        ESP_LOGI(
            TAG,
            "========================================"
        );


        // ====================================================
        // COUNTDOWN
        // ========================================================

        for (
            int seconds = 3;
            seconds >= 1;
            seconds--
        )
        {
            ESP_LOGI(
                TAG,
                "%d...",
                seconds
            );


            vTaskDelay(
                pdMS_TO_TICKS(
                    1200
                )
            );
        }


        // ====================================================
        // SPEAK
        // ========================================================

        ESP_LOGI(
            TAG,
            "========================================"
        );


        ESP_LOGI(
            TAG,
            "SPEAK NOW!"
        );


        ESP_LOGI(
            TAG,
            "Say the word anytime during the next %d seconds.",
            CAPTURE_SECONDS
        );


        ESP_LOGI(
            TAG,
            "Speak."
        );


        ESP_LOGI(
            TAG,
            "========================================"
        );


        // ====================================================
        // RECORD TWO SECONDS
        // ========================================================

        if (
            !record_two_seconds(
                capture.data()
            )
        )
        {
            ESP_LOGE(
                TAG,
                "Recording failed."
            );


            vTaskDelay(
                pdMS_TO_TICKS(
                    3000
                )
            );


            continue;
        }


        // ====================================================
        // SELECT BEST ONE-SECOND WINDOW
        // ========================================================

        if (
            !select_best_one_second(
                capture.data(),
                audio.data()
            )
        )
        {
            ESP_LOGE(
                TAG,
                "Could not select speech window."
            );


            vTaskDelay(
                pdMS_TO_TICKS(
                    3000
                )
            );


            continue;
        }


        // ====================================================
        // SILENCE CHECK
        // ========================================================

        if (
            last_audio_rms <
            SILENCE_RMS_THRESHOLD
        )
        {
            printf("\n");


            printf(
                "========================================\n"
            );


            printf(
                "LIVE KEYWORD RESULT\n"
            );


            printf(
                "========================================\n"
            );


            printf(
                "SILENCE / TOO QUIET\n"
            );


            printf(
                "Audio RMS : %.6f\n",
                last_audio_rms
            );


            printf(
                "Threshold : %.6f\n",
                SILENCE_RMS_THRESHOLD
            );


            printf(
                "Model was NOT run.\n"
            );


            printf(
                "LED was NOT changed.\n"
            );


            printf(
                "========================================\n"
            );


            printf("\n");


            ESP_LOGI(
                TAG,
                "Next test in 3 seconds..."
            );


            vTaskDelay(
                pdMS_TO_TICKS(
                    3000
                )
            );


            continue;
        }


        // ====================================================
        // CLIPPING CHECK
        // ========================================================

        if (
            last_clipped_fraction >
            MAX_CLIPPED_FRACTION
        )
        {
            printf("\n");


            printf(
                "========================================\n"
            );


            printf(
                "AUDIO CLIPPED\n"
            );
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

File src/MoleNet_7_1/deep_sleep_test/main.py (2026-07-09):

from machine import SoftSPI, Pin
from SX1262 import Transceiver
from LoRaWAN import LoRaWAN
from config_OTAA import DevEUI, JoinEUI, AppKey
import EU868
import machine
import esp32
import utime
import struct

# --------------------------------------------------
# MoleNet v7.1 Board + LoRa Deep Sleep Test
# --------------------------------------------------

SLEEP_MINUTES = 60
SLEEP_MS = SLEEP_MINUTES * 60 * 1000

# MoleNet v7.1 SX1262 pin mapping
LORA_SCK = 14
LORA_MOSI = 47
LORA_MISO = 21
LORA_CS = 48
LORA_RST = 15
LORA_BUSY = 39
LORA_DIO1 = 46

# Board LEDs
LED1_PIN = 2
LED2_PIN = 38

JOIN_SF = 7
SEND_SF = 7
SEND_POWER = 17

# Set True only if a fresh OTAA join is needed every boot
FORCE_OTAA_JOIN_EVERY_BOOT = False


def release_pin_holds():
    try:
        esp32.gpio_deep_sleep_hold(False)
        print("Released deep sleep pin holds")
    except Exception as e:
        print("Hold release error:", e)

    pins = [
        LORA_CS, LORA_RST, LORA_SCK, LORA_MOSI,
        LORA_MISO, LORA_BUSY, LORA_DIO1,
        LED1_PIN, LED2_PIN
    ]

    for pin_no in pins:
        try:
            Pin(pin_no, Pin.IN, hold=False)
        except Exception:
            pass


def disable_wifi_ble():
    try:
        import network
        network.WLAN(network.STA_IF).active(False)
        network.WLAN(network.AP_IF).active(False)
        print("WiFi disabled")
    except Exception as e:
        print("WiFi disable error:", e)

    try:
        import bluetooth
        bluetooth.BLE().active(False)
        print("BLE disabled")
    except Exception as e:
        print("BLE disable error:", e)


def leds_off():
    try:
        Pin(LED1_PIN, Pin.OUT, value=0)
        Pin(LED2_PIN, Pin.OUT, value=0)
        print("LEDs off")
    except Exception as e:
        print("LED off error:", e)
        
def wait_lora_not_busy(timeout_ms=1000):
    busy = Pin(LORA_BUSY, Pin.IN)
    start = utime.ticks_ms()

    while busy.value() == 1:
        if utime.ticks_diff(utime.ticks_ms(), start) > timeout_ms:
            print("LoRa BUSY wait timeout")
            break
        utime.sleep_ms(10)

    print("LoRa BUSY is LOW")

def lora_sleep_and_prepare_pins(sx):
    try:
        if sx is not None:
            sx.sleep()
            print("SX1262 sleep() called")
            
            # Wait until SX1262 finishes processing the sleep command
            wait_lora_not_busy(timeout_ms=1000)
            utime.sleep_ms(50)
    except Exception as e:
        print("SX1262 sleep error:", e)

    try:
        Pin(LORA_CS, Pin.OUT, value=1, hold=True)
        Pin(LORA_RST, Pin.OUT, value=1, hold=True)
        Pin(LORA_SCK, Pin.OUT, value=0, hold=True)
        Pin(LORA_MOSI, Pin.OUT, value=0, hold=True)

        Pin(LORA_MISO, Pin.IN)
        Pin(LORA_BUSY, Pin.IN)
        Pin(LORA_DIO1, Pin.IN)

        print("LoRa pins prepared for deep sleep")
    except Exception as e:
        print("LoRa pin preparation error:", e)


def go_to_deep_sleep(sx):
    print("Preparing for deep sleep")

    lora_sleep_and_prepare_pins(sx)

    try:
        Pin(LED1_PIN, Pin.OUT, value=0, hold=True)
        Pin(LED2_PIN, Pin.OUT, value=0, hold=True)
    except Exception:
        pass

    try:
        esp32.gpio_deep_sleep_hold(False)
        print("Deep sleep holds disabled")
    except Exception as e:
        print("Deep sleep hold error:", e)

    print("Going to deep sleep for", SLEEP_MINUTES, "minutes")
    utime.sleep_ms(500)
    machine.deepsleep(SLEEP_MS)


print()
print("Booting MoleNet v7.1 LoRa deep sleep test")
print("Wake reason:", machine.wake_reason())
print("Sleep interval:", SLEEP_MINUTES, "minutes")

if machine.reset_cause() != machine.DEEPSLEEP_RESET:
    print("Physical reset or fresh boot. Waiting 1 second for Thonny...")
    utime.sleep_ms(1000)
else:
    print("Deep sleep wakeup. Skipping boot delay...")

release_pin_holds()
disable_wifi_ble()
leds_off()

# Boot counter stored in RTC memory
rtc = machine.RTC()
rtc_data = rtc.memory()

if len(rtc_data) >= 4:
    boot_count = struct.unpack("<I", rtc_data[:4])[0]
else:
    boot_count = 0

boot_count += 1
rtc.memory(struct.pack("<I", boot_count))

print("Boot count:", boot_count)

sx = None
lw = None

try:
    print("Initializing SX1262 LoRa")

    spi = SoftSPI(
        baudrate=100000,
        polarity=0,
        phase=0,
        sck=Pin(LORA_SCK),
        mosi=Pin(LORA_MOSI),
        miso=Pin(LORA_MISO)
    )

    cs = Pin(LORA_CS, Pin.OUT, value=1)
    rst = Pin(LORA_RST, Pin.OUT, value=1)
    busy = Pin(LORA_BUSY, Pin.IN)
    dio1 = Pin(LORA_DIO1, Pin.IN)

    sx = Transceiver(spi, cs, rst, busy, dio1)
    lw = LoRaWAN(sx, EU868.FREQS)

except Exception as e:
    print("LoRa init error:", e)
    go_to_deep_sleep(sx)


try:
    if FORCE_OTAA_JOIN_EVERY_BOOT:
        print("Forcing fresh OTAA join")
        lw.joined = False
        lw.join_otaa(AppKey, JoinEUI, DevEUI, retries=5, sf=JOIN_SF)

    elif not lw.joined:
        print("No saved LoRaWAN session. Trying OTAA join")
        lw.join_otaa(AppKey, JoinEUI, DevEUI, retries=5, sf=JOIN_SF)

    else:
        print("Using saved LoRaWAN session")

    print("Joined =", lw.joined)

    if lw.joined:
        payload = struct.pack("<f", float(boot_count))

        print("Payload length:", len(payload), "bytes")
        print("Sending boot count to TTN")

        lw.send(payload, power=SEND_POWER, sf=SEND_SF)

        print("Payload sent successfully")

    else:
        print("Join failed. Sleeping anyway")

except Exception as e:
    print("LoRaWAN send error:", e)


go_to_deep_sleep(sx)

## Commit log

2025-12-15 Tidy up repo
    [Molenet_V6.4_26_08_25.kicad_pcb, Molenet_V6.4_26_08_25.kicad_sch, Molenet_V7.0_03_12_25.kicad_pcb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]
2026-01-16 Simple test script for new 7.0 boards
2026-03-05 rename dir
    [Molenet_V7.1_04_03_26.kicad_pcb, Molenet_V7.1_04_03_26.kicad_sch, Molenet_V7.1_Part_List.csv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]
2026-03-05 Rename some experiment directories
    [Field_experiment_2020_06_12.ods, Field_experiment_2020_06_16.ods, Field_experiment_2020_06_18.ods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]
2026-03-05 Do not use the water sensor dir as a submodule
2026-06-26 Update LoRaWAN Setup documentation
    Removed instructions for unique TTN end device ID generation and example output.
2026-06-28 Power measurement and battery voltager reader software and documentation
    [BKmoleNET-Data - data.csv, CNMoleNET-Data - data.csv]
2026-07-09 Add getting started guide for MoleNet boards
    This guide provides steps to identify hardware versions, find appropriate software, documentation, experiments, schematics, and maintenance tools for MoleNet boards.
2026-07-26 Add Getting Started guide for MoleNet
    This document provides a comprehensive guide for users to identify their MoleNet board version and access relevant software, hardware documentation, experiments, and setup resources.
2026-07-26 README with Getting Started Guide
    Added a 'Getting Started Guide' for new users to help identify board versions and find documentation.
